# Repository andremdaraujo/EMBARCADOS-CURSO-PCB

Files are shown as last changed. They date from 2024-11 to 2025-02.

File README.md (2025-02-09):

# PROJETO DE PCB PARA SISTEMAS EMBARCADOS
  
Esta é uma placa de desenvolvimento educacional concebida como parte curso 
[**Projeto e PCB para Sistemas Embarcados**]( https://cursos.embarcados.com.br/cursos/projeto-de-pcb-para-sistemas-embarcados/). 
O curso é oferecido em parceria com o [**Portal Embarcados**](https://embarcados.com.br/).
Durante o curso, todas as etapas de projeto e desenvolvimento desta placa são mostradas, passo a passo. 
Neste repositório, é possível acessar a todos os arquivos de projeto e fabricação.

## Licença
Este é um projeto Open Source, licenciado sob a CERN-OHL-P. Mais detalhes em [LICENSE.md](./LICENSE.md).  
A placa desenvolvida durante o curso foi baseada no projeto [**STM32 Explorer Board - STM32XP**](https://github.com/MechatronixLab/STM32XP), 
que também é licenciado conforme a CERN-OHL-P e certificado pela OSWHA ([OSHW BR000018](https://certification.oshwa.org/br000018.html)).

## Especificações da placa

A placa é baseado no [**STM32F411**](https://www.st.com/en/microcontrollers-microprocessors/stm32f411.html), mais especificamente, o [**STM32F411RET6**](https://www.st.com/en/microcontrollers-microprocessors/stm32f411re.html).
Além disso, a placa apresenta alguns componentes comumente usados em sistemas embarcados, como:
- Conversores DC-DC
- Display OLED, conectado ao MCU via I²C
- LEDs RGB
- Áudio (Buzer Piezoelérico), controlada via PWM
- ADC externo com filtros antialiasing analógicos
- USB 1.1 Full Speed via conector Tipo C
- Cartão Micro SD para fácil armazenamento de dados, conectado ao MCU via SPI
- Botões conectados a pinos de entrada do MCU, além de botões para RESET e BOOT
- Vários pinos de GPIO roteados para conectores/pinos de breakout
- Bateria CR2032 para operação RTC

A placa pode ser utilizada em modo Standalone ou conectada a uma protoboard, dependendo da escolha de conectores:

Top

Bottom

Protoboard
  
## Firmware

Esta placa pode executar a aplicação de demonstração desenvolvida no projeto [STM32 Explorer Board - STM32XP](https://github.com/MechatronixLab/STM32XP).

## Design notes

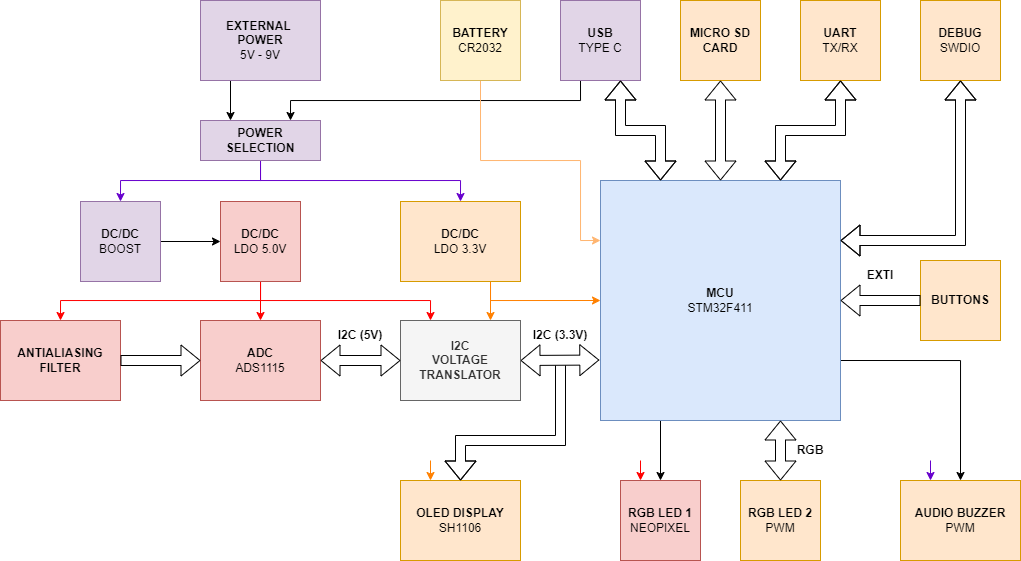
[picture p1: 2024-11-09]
DOC/PROTOTYPE/STM32XP REV.00 - HARDWARE BLOCK DIAGRAM.png

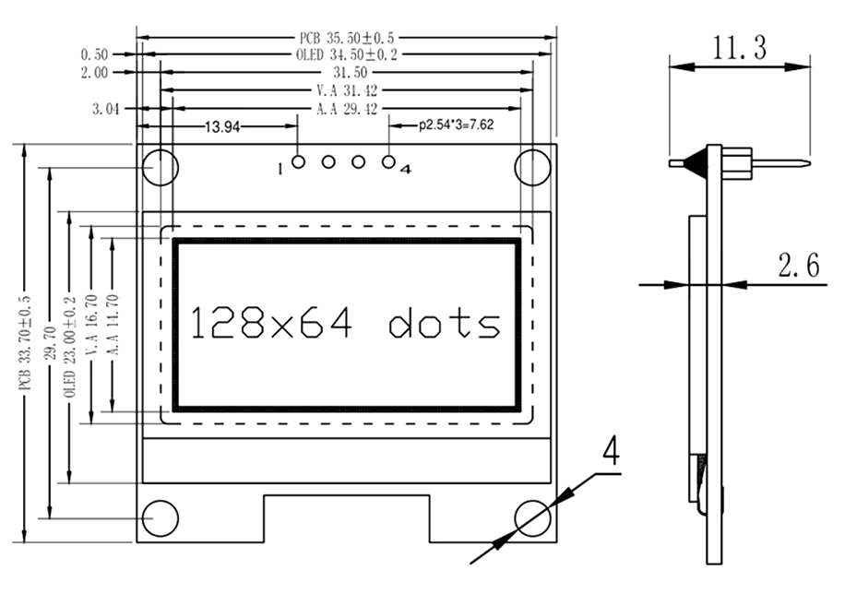
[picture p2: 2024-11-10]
DOC/DATASHEETS/OLED 1.3in - MECHANICAL DRAWING.png

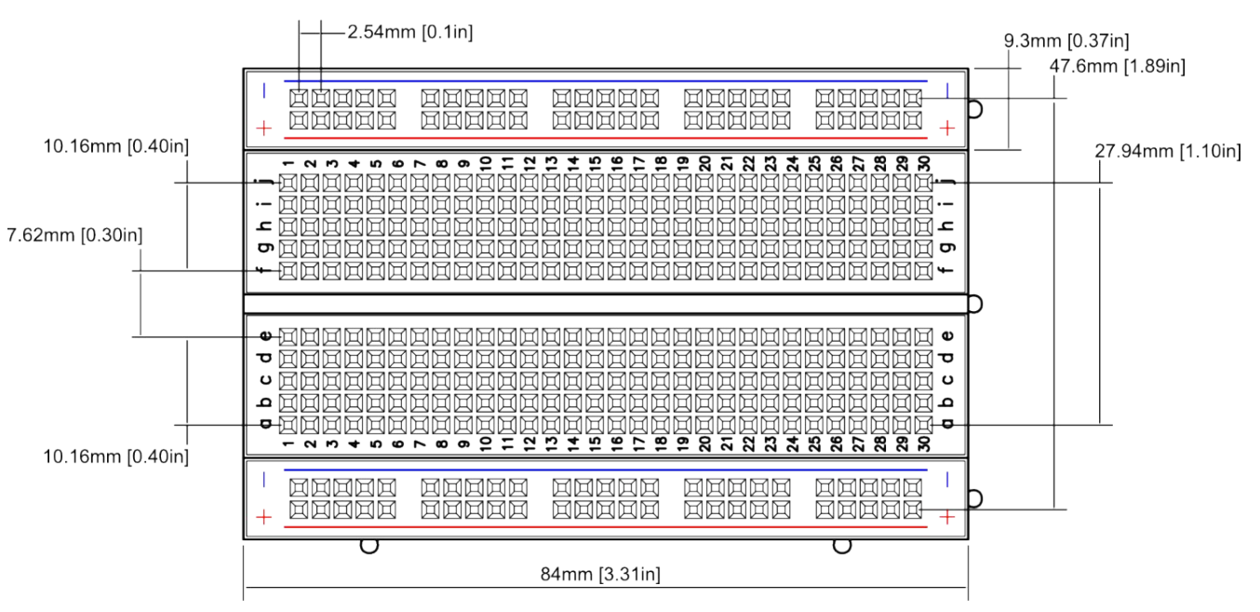
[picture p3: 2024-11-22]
HARDWARE/3D MODELS/p-pc-bb400_dimensions.png

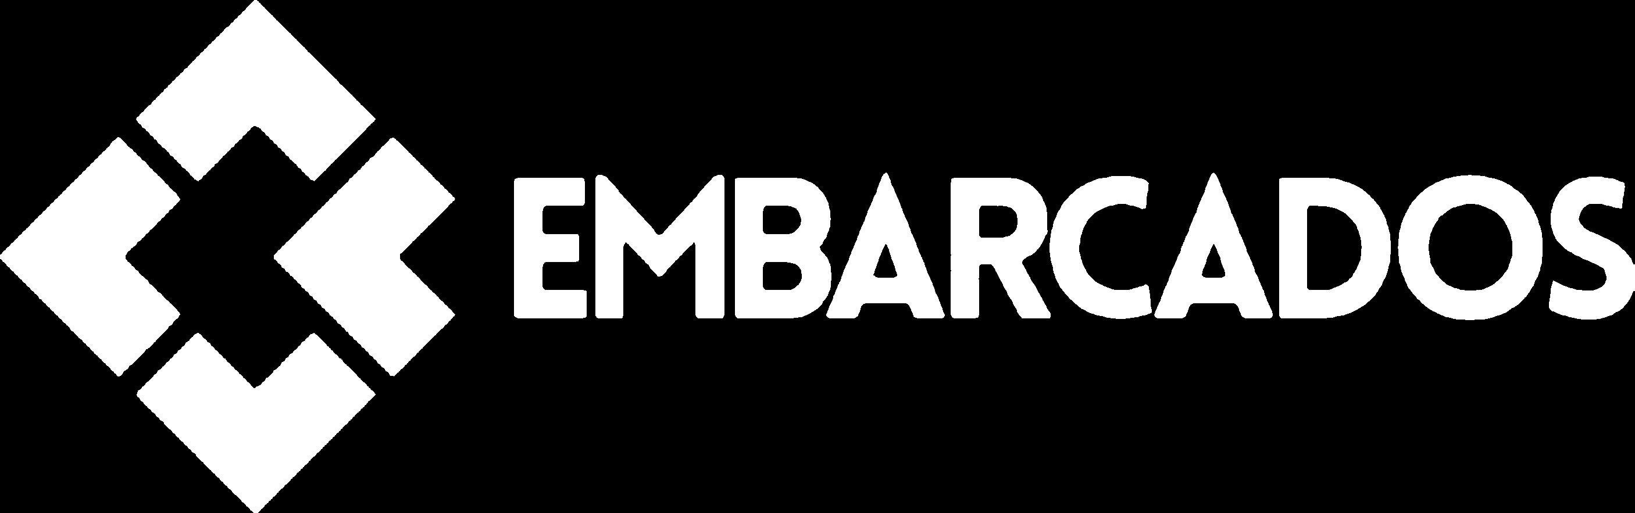
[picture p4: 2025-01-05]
DOC/IMAGES/EMBARCADOS BW.bmp

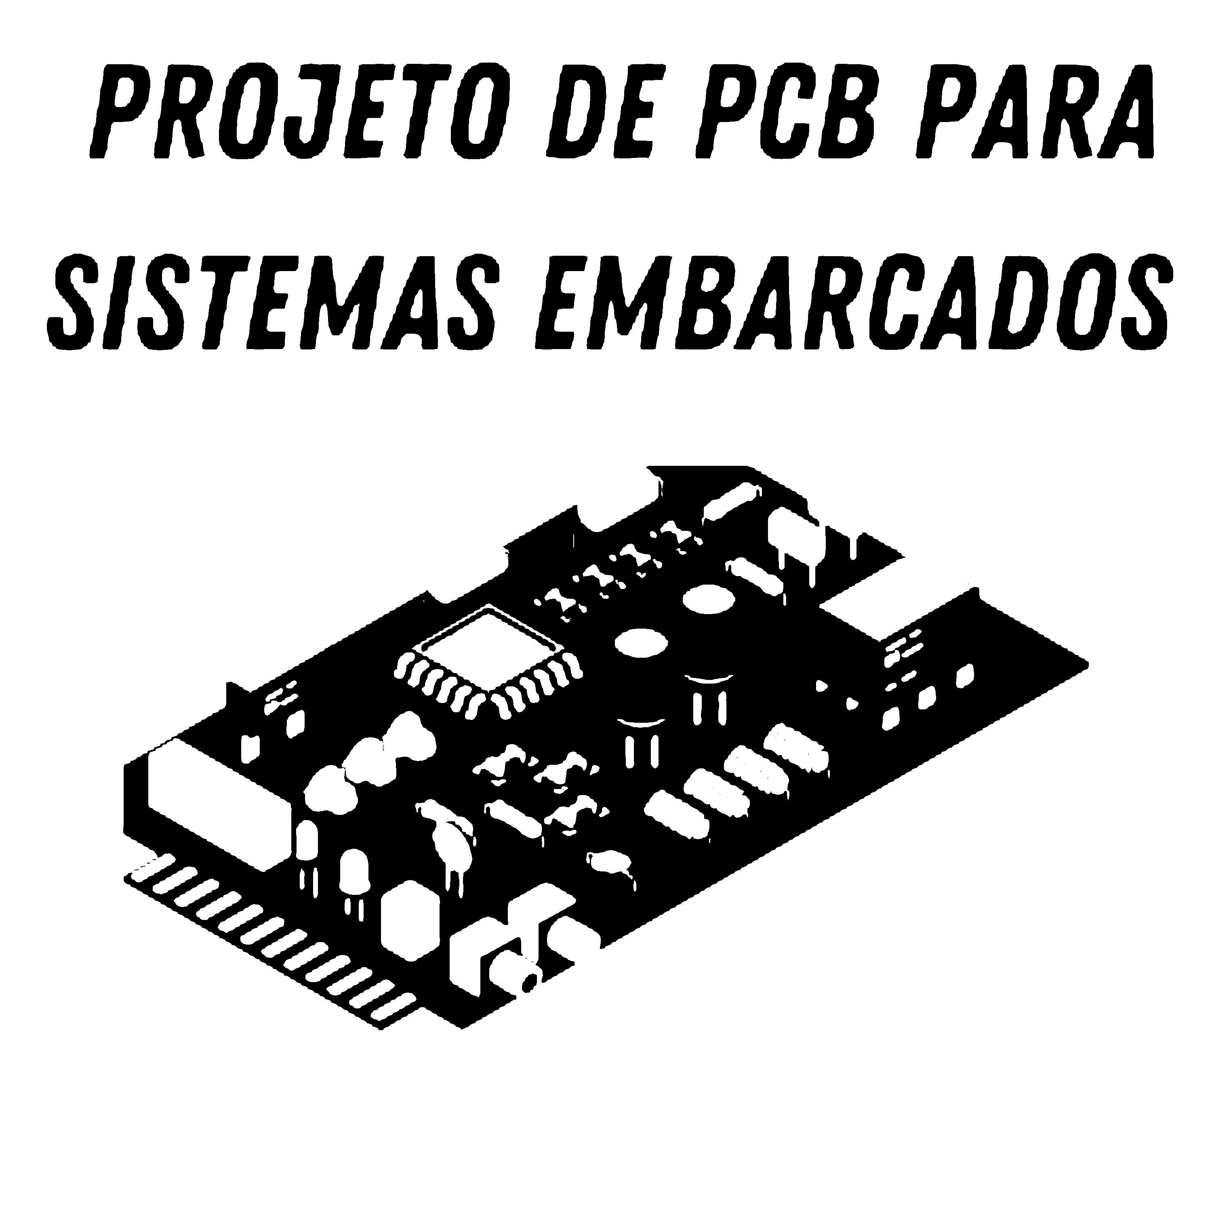
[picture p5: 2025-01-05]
DOC/IMAGES/CURSO PCB BW.bmp

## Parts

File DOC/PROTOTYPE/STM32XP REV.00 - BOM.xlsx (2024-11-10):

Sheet: STM32XP - BOM REV.00
 |  |  |  |  | SPEC |  |  |  |  | JLCPCB
# | DESIGNATOR | VALUE | FOOTPRINT | QTY. | MPN | MANUFACTURER | DATASHEET | 3D MODEL | NOTES | LCSC Part # | LCSC MPN | LCSC MANUFACTURER
1 | BT1 | CR2032 | CR2032 | 1 | 79527141 | WÜRTH ELEKTRONIK | https://www.we-online.com/components/products/datasheet/79527141.pdf | https://www.we-online.com/components/products/download/79527141%20%28rev1%29.igs | - | - | - | -
2 | C1, C10, C13, C19, C2, C27, C29, C36, C37, C4, C40, C44, C6, C7, C8, C9 | 10uF 16V | CAP_0805 | 16 | KGM21AR71C106K | KYOCERA/AVX | https://datasheets.kyocera-avx.com/KGM_X7R.pdf | KICAD CAP 0603 | - | C15850 (https://www.lcsc.com/product-detail/Multilayer-Ceramic-Capacitors-MLCC-SMD-SMT_Samsung-Electro-Mechanics-CL21A106KAYNNNE_C15850.html) | CL21A106KAYNNNE | SAMSUNG
3 | C11, C12, C17, C18, C20, C21, C22, C23, C24, C26, C28, C3, C30, C32, C33, C34, C35, C38, C39, C41, C42, C43, C45, C5 | 100nF 50V | CAP_0603 | 24 | KGM15BR71H104K | KYOCERA/AVX | https://datasheets.kyocera-avx.com/KGM_X7R.pdf | KICAD CAP 0603 | - | C14663 (https://www.lcsc.com/product-detail/Multilayer-Ceramic-Capacitors-MLCC-SMD-SMT_YAGEO-CC0603KRX7R9BB104_C14663.html) | CC0603KRX7R9BB104 | YAGEO
4 | C14, C15, C25, C31 | 10pF 50V | CAP_0603 | 4 | KGM15ACG1H100G | KYOCERA/AVX | https://datasheets.kyocera-avx.com/C0GNP0-KGM.pdf | KICAD CAP 0603 | - | C1634 (https://www.lcsc.com/product-detail/Multilayer-Ceramic-Capacitors-MLCC-SMD-SMT_Samsung-Electro-Mechanics-CL10C100JB8NNNC_C1634.html) | CL10C100JB8NNNC | SAMSUNG
5 | C16 | 680nF 16V | CAP_0603 | 1 | KGM15BR71C684M | KYOCERA/AVX | https://datasheets.kyocera-avx.com/KGM_X7R.pdf | KICAD CAP 0603 | - | C327005 (https://www.lcsc.com/product-detail/Multilayer-Ceramic-Capacitors-MLCC-SMD-SMT_YAGEO-CC0603KRX5R8BB684_C327005.html) | CC0603KRX5R8BB684 | YAGEO
6 | D1, D3, D4, D7, D8 | LED | LED_0603 | 5 | 150060SS55040 | WÜRTH ELEKTRONIK | https://www.we-online.com/components/products/datasheet/150060SS55040.pdf | KICAD LED 0603 | - | C128052 (https://www.lcsc.com/product-detail/LED-Indication-Discrete_Everlight-Elec-19-213-R6C-AM2P1VY-3T_C128052.html) | 19-213/R6C-AM2P1VY/3T | EVERLIGHT
7 | D10 | 150505M173300 | WE 150505M173300 | 1 | 150505M173300 | WÜRTH ELEKTRONIK | https://www.we-online.com/components/products/datasheet/150505M173300.pdf | https://www.we-online.com/components/products/download/Download_IGS-WL-SFTW-150505M173300%20%28rev1%29.igs | - | - | - | -
8 | D2 | STPS1L40-Y | D_SOD-123 | 1 | STPS1L40ZFY | STMICROELECTRONICS | https://www.st.com/resource/en/datasheet/stps1l40-y.pdf | KICAD SOD-123 | - | C82544 (https://www.lcsc.com/product-detail/Schottky-Diodes_Diodes-Incorporated-1N5819HW-7-F_C82544.html) | 1N5819HW-7-F | DIODES INCORPORATED
9 | D5 | WS2812B | LED_WS2812B_PLCC4_5.0x5.0mm_P3.2mm | 1 | 1315050930002 | WÜRTH ELEKTRONIK | https://www.we-online.com/components/products/datasheet/1315050930002.pdf | https://www.we-online.com/components/products/download/IGS_WL-ICLED_1315050930002%20%28rev1%29.igs | - | - | - | -
10 | D6 | BAT54C | SOT-23 | 1 | BAT54C-7-F | DIODES INCORPORATED | https://www.diodes.com/datasheet/download/BAT54C.pdf | KICAD SOT-23-3 | CHANGE TO 2X 1N5819HW | C916424 (https://www.lcsc.com/product-detail/Schottky-Diodes_JSMSEMI-BAT54C_C916424.html) | BAT54C | JSMSEMI
11 | D9 | ESDA6V1-5SC6 | SOT-23-6 | 1 | ESDA6V1-5SC6 | STMICROELECTRONICS | https://www.st.com/resource/en/datasheet/esda6v1-5sc6.pdf | KICAD SOT-23-6 | - | C2827672 (https://www.lcsc.com/product-detail/ESD-and-Surge-Protection-TVS-ESD_TECH-PUBLIC-ESDA6V1-5SC6_C2827672.html) | ESDA6V1-5SC6 | TECH PUBLIC
12 | FB1, FB2, FB3 | 600R | 0603 | 3 | 742792651 | WÜRTH ELEKTRONIK | https://www.we-online.com/components/products/datasheet/742792651.pdf | KICAD FB 0603 | - | C963865 (https://www.lcsc.com/product-detail/Ferrite-Beads_HYHONGYEX-ACMS160808A1213A_C963865.html) | ACMS160808A1213A | HYHONGYEX
13 | FID1, FID2, FID3 | Fiducial | Fiducial_0.75mm_Mask1.5mm | 3 | - | - | - | - | DO NOT PLACE | - | - | -
14 | H1, H2, H3, H4 | MountingHole | MountingHole_3.2mm_M3 | 4 | - | - | - | - | DO NOT PLACE | - | - | -
15 | J1, J6 | Conn_01x20_Socket | PinSocket_1x20_P2.54mm_Horizontal | 2 | 613020143121 | WÜRTH ELEKTRONIK | https://www.we-online.com/components/products/datasheet/613020143121.pdf | https://www.we-online.com/components/products/download/613020143121%20%28rev1%29.igs | THRU HOLE | - | - | -
16 | J2 | Jack-DC | BarrelJack_GCT_DCJ200-10-A_Horizontal | 1 | 694108301002 | WÜRTH ELEKTRONIK | https://www.we-online.com/components/products/datasheet/694108301002.pdf | https://www.we-online.com/components/products/download/Download_IGES_694108301002%20%28rev1%29.iges | THRU HOLE | - | - | -
17 | J3 | Conn_02x05_Odd_Even | PinSocket_2x05_P2.54mm_Horizontal | 1 | 613010243121 | WÜRTH ELEKTRONIK | https://www.we-online.com/components/products/datasheet/613010243121.pdf | https://www.we-online.com/components/products/download/Downloads_613010243121%20%28rev1%29.iges | THRU HOLE | - | - | -
18 | J4 | USB TYPE C | USB_C_Receptacle_G-Switch_GT-USB-7010ASV | 1 | 629722000214 | WÜRTH ELEKTRONIK | https://www.we-online.com/components/products/datasheet/629722000214.pdf | https://www.we-online.com/components/products/download/IGES_629722000214%20%28rev1%29.iges | - | C2927038 (https://www.lcsc.com/product-detail/USB-Connectors_DEALON-USB-TYPE-C-018_C2927038.html) | USB-TYPE-C-018 | DEALON
19 | J5 | MICRO SD | WE 693071020811 | 1 | 693071020811 | WÜRTH ELEKTRONIK | https://www.we-online.com/components/products/datasheet/693071020811.pdf | https://www.we-online.com/components/products/download/Download_IGES_693071020811%20%28rev1%29.iges | - | C19189038 (https://www.lcsc.com/product-detail/SD-Card-Memory-Card-Connector_hanxia-HX-TF-CARD-H1-8-SY_C19189038.html) | HX TF-CARD H1.8 SY | HANXIA
20 | JP1 | 9V | SolderJumper | 1 | - | - | - | - | DO NOT PLACE | - | - | -
21 | JP2 | VSEL | SolderJumper | 1 | - | - | - | - | DO NOT PLACE | - | - | -
22 | L1 | 10uH | WE 74404024100 | 1 | 74404024100 | WÜRTH ELEKTRONIK | https://www.we-online.com/components/products/datasheet/74404024100.pdf | https://www.we-online.com/components/products/download/WE-LQS_252012%20%28rev1%29.igs | - | C520138 (https://www.lcsc.com/product-detail/Power-Inductors_Cybermax-CMLW252012P100MST_C520138.html) | CMLW252012P100MST | CYBERMAX
23 | L2 | 744232090 | WE 744232090 | 1 | 744232090 | WÜRTH ELEKTRONIK | https://www.we-online.com/components/products/datasheet/744232090.pdf | https://www.we-online.com/components/products/download/WE-CNSW_1206_CNSW%20%28rev1%29.igs | - | - | - | -
24 | L3 | L_Small | IND_0603 | 1 | 742792651 | WÜRTH ELEKTRONIK | https://www.we-online.com/components/products/datasheet/742792651.pdf | KICAD FB 0603 | - | C963865 (https://www.lcsc.com/product-detail/Ferrite-Beads_HYHONGYEX-ACMS160808A1213A_C963865.html) | ACMS160808A1213A | HYHONGYEX
25 | LS1 | 78dB 4kHz | PKM13EPYH4000-A0 | 1 | PKM13EPYH4000-A0 | MURATA | https://www.murata.com/en-us/products/productdetail?partno=PKM13EPYH4000-A0 | https://www.murata.com/en-us/products/productdetail?partno=PKM13EPYH4000-A0 | THRU HOLE | - | - | -
26 | Q1, Q2, Q3 | 2N7002 | SOT-23 | 3 | 2N7002K-7 | DIODES INCORPORATED | https://www.diodes.com/datasheet/download/2N7002K.pdf | KICAD SOT-23-3 | - | C8545 (https://www.lcsc.com/product-detail/MOSFETs_Jiangsu-Changjing-Electronics-Technology-Co-Ltd-2N7002_C8545.html) | 2N7002 | JIANGSU CHANGJING
27 | R1, R11, R13, R14, R18, R2, R21, R24, R25, R26, R27, R32, R35, R36, R37, R39, R40, R41, R45, R46, R47, R48, R49, R50, R51, R52, R53 | 10K 1% | RES_0603 | 27 | CRCW060310K0FK | VISHAY | https://www.we-online.com/components/products/datasheet/61300411821.pdf | KICCAD RES 0603 | - | C25804 (https://www.lcsc.com/product-detail/Chip-Resistor-Surface-Mount_UNI-ROYAL-Uniroyal-Elec-0603WAF1002T5E_C25804.html) | 0603WAF1002T5E | UNI-ROYAL
28 | R10, R22, R30, R31, R33, R34, R8, R9 | 1K 1% | RES_0603 | 8 | CRCW06031K00FK | VISHAY | https://www.we-online.com/components/products/datasheet/61300411821.pdf | KICCAD RES 0603 | - | C21190 (https://www.lcsc.com/product-detail/Chip-Resistor-Surface-Mount_UNI-ROYAL-Uniroyal-Elec-0603WAF1001T5E_C21190.html) | 0603WAF1001T5E | UNI-ROYAL
29 | R12, R15 | 2.2K 1% | RES_0603 | 2 | CRCW06032K20FK | VISHAY | https://www.we-online.com/components/products/datasheet/61300411821.pdf | KICCAD RES 0603 | - | C4190 (https://www.lcsc.com/product-detail/Chip-Resistor-Surface-Mount_UNI-ROYAL-Uniroyal-Elec-0603WAF2201T5E_C4190.html) | 0603WAF2201T5E | UNI-ROYAL
30 | R16, R17, R19, R20, R38, R4, R42, R43, R44, R5, R6, R7 | 51R 1% | RES_0603 | 12 | CRCW060351R0FK | VISHAY | https://www.we-online.com/components/products/datasheet/61300411821.pdf | KICCAD RES 0603 | - | C23197 (https://www.lcsc.com/product-detail/Chip-Resistor-Surface-Mount_UNI-ROYAL-Uniroyal-Elec-0603WAF510JT5E_C23197.html) | 0603WAF510JT5E | UNI-ROYAL
31 | R23, R28 | 5.1K 1% | RES_0603 | 2 | CRCW06035K10FK | VISHAY | https://www.we-online.com/components/products/datasheet/61300411821.pdf | KICCAD RES 0603 | - | C23186 (https://www.lcsc.com/product-detail/Chip-Resistor-Surface-Mount_UNI-ROYAL-Uniroyal-Elec-0603WAF5101T5E_C23186.html) | 0603WAF5101T5E | UNI-ROYAL
32 | R29 | 0R | RES_0603 | 1 | CRCW06030000Z0 | VISHAY | https://www.we-online.com/components/products/datasheet/61300411821.pdf | KICCAD RES 0603 | - | C21189 (https://www.lcsc.com/product-detail/Chip-Resistor-Surface-Mount_UNI-ROYAL-Uniroyal-Elec-0603WAF0000T5E_C21189.html) | 0603WAF0000T5E | UNI-ROYAL
33 | R3 | 6K2 1% | RES_0603 | 1 | CRCW06036K20FK | VISHAY | https://www.we-online.com/components/products/datasheet/61300411821.pdf | KICCAD RES 0603 | - | C4260 (https://www.lcsc.com/product-detail/Chip-Resistor-Surface-Mount_UNI-ROYAL-Uniroyal-Elec-0603WAF6201T5E_C4260.html) | 0603WAF6201T5E | UNI-ROYAL
34 | SW1 | RST | SW_Push_1P1T_NO_CK_KSC6xxJ | 1 | PTS526SM20SMTR21 LFS | LITTELFUSE/C&K | https://www.ckswitches.com/media/2780/pts526.pdf | https://www.ckswitches.com/products/switches/product-details/Tactile/PTS526/PTS526SM20SMTR21%20LFS/ | ${KICAD8_3DMODEL_DIR}/Button_Switch_SMD.3dshapes/SW_SPST_TL3342.step | C318884 (https://www.lcsc.com/product-detail/Tactile-Switches_XKB-Connection-TS-1187A-B-A-B_C318884.html) | TS-1187A-B-A-B | XKB CONNECTION
35 | SW2 | UP | SW_Push_1P1T_NO_CK_KSC6xxJ | 1 | PTS526SM20SMTR21 LFS | LITTELFUSE/C&K | https://www.ckswitches.com/media/2780/pts526.pdf | https://www.ckswitches.com/products/switches/product-details/Tactile/PTS526/PTS526SM20SMTR21%20LFS/ | ${KICAD8_3DMODEL_DIR}/Button_Switch_SMD.3dshapes/SW_SPST_TL3342.step | C318884 (https://www.lcsc.com/product-detail/Tactile-Switches_XKB-Connection-TS-1187A-B-A-B_C318884.html) | TS-1187A-B-A-B | XKB CONNECTION
36 | SW3 | LEFT | SW_Push_1P1T_NO_CK_KSC6xxJ | 1 | PTS526SM20SMTR21 LFS | LITTELFUSE/C&K | https://www.ckswitches.com/media/2780/pts526.pdf | https://www.ckswitches.com/products/switches/product-details/Tactile/PTS526/PTS526SM20SMTR21%20LFS/ | ${KICAD8_3DMODEL_DIR}/Button_Switch_SMD.3dshapes/SW_SPST_TL3342.step | C318884 | TS-1187A-B-A-B | XKB CONNECTION
37 | SW4 | CENTER | SW_Push_1P1T_NO_CK_KSC6xxJ | 1 | PTS526SM20SMTR21 LFS | LITTELFUSE/C&K | https://www.ckswitches.com/media/2780/pts526.pdf | https://www.ckswitches.com/products/switches/product-details/Tactile/PTS526/PTS526SM20SMTR21%20LFS/ | ${KICAD8_3DMODEL_DIR}/Button_Switch_SMD.3dshapes/SW_SPST_TL3342.step | C318884 | TS-1187A-B-A-B | XKB CONNECTION
38 | SW5 | RIGHT | SW_Push_1P1T_NO_CK_KSC6xxJ | 1 | PTS526SM20SMTR21 LFS | LITTELFUSE/C&K | https://www.ckswitches.com/media/2780/pts526.pdf | https://www.ckswitches.com/products/switches/product-details/Tactile/PTS526/PTS526SM20SMTR21%20LFS/ | ${KICAD8_3DMODEL_DIR}/Button_Switch_SMD.3dshapes/SW_SPST_TL3342.step | C318884 | TS-1187A-B-A-B | XKB CONNECTION
39 | SW6 | BUTTON 1 | SW_Push_1P1T_NO_CK_KSC6xxJ | 1 | PTS526SM20SMTR21 LFS | LITTELFUSE/C&K | https://www.ckswitches.com/media/2780/pts526.pdf | https://www.ckswitches.com/products/switches/product-details/Tactile/PTS526/PTS526SM20SMTR21%20LFS/ | ${KICAD8_3DMODEL_DIR}/Button_Switch_SMD.3dshapes/SW_SPST_TL3342.step | C318884 | TS-1187A-B-A-B | XKB CONNECTION
40 | SW7 | BUTTON 2 | SW_Push_1P1T_NO_CK_KSC6xxJ | 1 | PTS526SM20SMTR21 LFS | LITTELFUSE/C&K | https://www.ckswitches.com/media/2780/pts526.pdf | https://www.ckswitches.com/products/switches/product-details/Tactile/PTS526/PTS526SM20SMTR21%20LFS/ | ${KICAD8_3DMODEL_DIR}/Button_Switch_SMD.3dshapes/SW_SPST_TL3342.step | C318884 | TS-1187A-B-A-B | XKB CONNECTION
41 | SW8 | DOWN | SW_Push_1P1T_NO_CK_KSC6xxJ | 1 | PTS526SM20SMTR21 LFS | LITTELFUSE/C&K | https://www.ckswitches.com/media/2780/pts526.pdf | https://www.ckswitches.com/products/switches/product-details/Tactile/PTS526/PTS526SM20SMTR21%20LFS/ | ${KICAD8_3DMODEL_DIR}/Button_Switch_SMD.3dshapes/SW_SPST_TL3342.step | C318884 | TS-1187A-B-A-B | XKB CONNECTION
42 | TP1, TP13, TP14, TP4 | GND | TestPoint_Keystone_5000-5004_Miniature | 4 | - | - | - | - | DO NOT PLACE | - | - | -
43 | TP10 | +3.3VA | TestPoint_Keystone_5000-5004_Miniature | 1 | - | - | - | - | DO NOT PLACE | - | - | -
44 | TP11 | +5VA | TestPoint_Keystone_5000-5004_Miniature | 1 | - | - | - | - | DO NOT PLACE | - | - | -
45 | TP12 | +VCORE | TestPoint_Keystone_5000-5004_Miniature | 1 | - | - | - | - | DO NOT PLACE | - | - | -
46 | TP15 | PD2 | TestPoint_THTPad_D1.0mm_Drill0.5mm | 1 | - | - | - | - | DO NOT PLACE | - | - | -
47 | TP16 | PC11 | TestPoint_THTPad_D1.0mm_Drill0.5mm | 1 | - | - | - | - | DO NOT PLACE | - | - | -
48 | TP17 | PC12 | TestPoint_THTPad_D1.0mm_Drill0.5mm | 1 | - | - | - | - | DO NOT PLACE | - | - | -
49 | TP18 | PB5 | TestPoint_THTPad_D1.0mm_Drill0.5mm | 1 | - | - | - | - | DO NOT PLACE | - | - | -
50 | TP19 | PB4 | TestPoint_THTPad_D1.0mm_Drill0.5mm | 1 | - | - | - | - | DO NOT PLACE | - | - | -
51 | TP2 | +5V | TestPoint_Keystone_5000-5004_Miniature | 1 | - | - | - | - | DO NOT PLACE | - | - | -
52 | TP20 | PC13 | TestPoint_THTPad_D1.0mm_Drill0.5mm | 1 | - | - | - | - | DO NOT PLACE | - | - | -
53 | TP21 | PB10 | TestPoint_THTPad_D1.0mm_Drill0.5mm | 1 | - | - | - | - | DO NOT PLACE | - | - | -
54 | TP3 | +3.3V | TestPoint_Keystone_5000-5004_Miniature | 1 | - | - | - | - | DO NOT PLACE | - | - | -
55 | TP5 | +9V | TestPoint_Keystone_5000-5004_Miniature | 1 | - | - | - | - | DO NOT PLACE | - | - | -
56 | TP6 | +VSEL | TestPoint_Keystone_5000-5004_Miniature | 1 | - | - | - | - | DO NOT PLACE | - | - | -
57 | TP7 | +VEXT | TestPoint_Keystone_5000-5004_Miniature | 1 | - | - | - | - | DO NOT PLACE | - | - | -
58 | TP8 | +VBUS | TestPoint_Keystone_5000-5004_Miniature | 1 | - | - | - | - | DO NOT PLACE | - | - | -
59 | TP9 | +3VBAT | TestPoint_Keystone_5000-5004_Miniature | 1 | - | - | - | - | DO NOT PLACE | - | - | -
60 | U1 | AMS1117-5.0 | SOT-223-3 | 1 | LD1117S50TR | STMICROELECTRONICS | https://www.st.com/resource/en/datasheet/ld1117.pdf | KICAD STO-223-3 | - | C6187 (https://www.lcsc.com/product-detail/Voltage-Regulators-Linear-Low-Drop-Out-LDO-Regulators_Advanced-Monolithic-Systems-AMS1117-5-0_C6187.html) | AMS1117-5.0 | ADVANCED MONOLITHIC SYSTEMS
61 | U2 | AMS1117-3.3 | SOT-223-3 | 1 | LD1117S33TR | STMICROELECTRONICS | https://www.st.com/resource/en/datasheet/ld1117.pdf | KICAD STO-223-3 | - | C6186 (https://www.lcsc.com/product-detail/Voltage-Regulators-Linear-Low-Drop-Out-LDO-Regulators_Advanced-Monolithic-Systems-AMS1117-3-3_C6186.html) | AMS1117-3.3 | ADVANCED MONOLITHIC SYSTEMS
62 | U3 | AP3012 | SOT-23-5 | 1 | AP3012KTR-E1 | DIODES INCORPORATED | https://www.diodes.com/datasheet/download/AP3012.pdf | KICAD SOT-23-5 | - | C460356 (https://www.lcsc.com/product-detail/DC-DC-Converters_Diodes-Incorporated-AP3012KTR-E1_C460356.html) | AP3012KTR-E1 | DIODES INCORPORATED
63 | U4 | OLED 128x64 1.3" | OLED 128x64 1.3in | 1 | 61300411821 | WÜRTH ELEKTRONIK | https://www.we-online.com/components/products/datasheet/61300411821.pdf | https://www.we-online.com/components/products/download/61300411821%20%28rev1%29.iges | THRU HOLE; https://grabcad.com/library/oled-screen-1-3-1 | - | - | -
64 | U5 | USBLC6-2SC6 | SOT-23-6 | 1 | USBLC6-2SC6 | STMICROELECTRONICS | https://www.st.com/resource/en/datasheet/usblc6-2sc6y.pdf | KICAD SOT-23-6 | - | C2827654 (https://www.lcsc.com/product-detail/ESD-and-Surge-Protection-TVS-ESD_TECH-PUBLIC-USBLC6-2SC6_C2827654.html) | USBLC6-2SC6 | TECH PUBLIC
65 | U6 | LM324 | TSSOP-14_4.4x5mm_P0.65mm | 1 | LMV324IPT | STMICROELECTRONICS | https://www.st.com/resource/en/datasheet/lmv324.pdf | KICAD TSSOP-14 | - | C398929 (https://www.lcsc.com/product-detail/Operational-Amplifier_Texas-Instruments-LMV324IPWR_C398929.html) | LMV324IPWR | TEXAS INSTRUMENTS
66 | U7 | ADS1115IDGS | TSSOP-10_3x3mm_P0.5mm | 1 | ADS1115IDGSR | TEXAS INSTRUMENTS | https://www.ti.com/lit/ds/symlink/ads1115.pdf | KICAD TSSOP-10 | - | C37593 (https://www.lcsc.com/product-detail/Analog-to-Digital-Converters-ADC_Texas-Instruments-ADS1115IDGSR_C37593.html) | ADS1115IDGSR | TEXAS INSTRUMENTS
67 | U8 | STM32F411RETx | LQFP-64_10x10mm_P0.5mm | 1 | STM32F411RET6 | STMICROELECTRONICS | https://www.st.com/resource/en/datasheet/stm32f411re.pdf | KICAD LQFP-64 | - | C94355 (https://www.lcsc.com/product-detail/Microcontrollers-MCU-MPU-SOC_STMicroelectronics-STM32F411RET6_C94355.html) | STM32F411RET6 | STMICROELECTRONICS
68 | Y1 | 32.768kHz 12.5pF | XTAL_2PIN_3.2x1.5mm | 1 | ABS06-32.768KHZ-T | ABRACON/FOX | https://abracon.com/Resonators/ABS06.pdf | KICAD XTAL 3.2x1.5 | - | C5563819 (https://www.lcsc.com/product-detail/Crystals_HCI-3131M-32768DT06LLL_C5563819.html) | 3131M-32768DT06LLL | HCI
69 | Y2 | 12MHz 20ppm 18pF | XTAL_4PIN_3.2x2.5mm | 1 | ABM8-12.000MHZ-D2Y-T | ABRACON/FOX | https://abracon.com/Resonators/abm8.pdf | KICAD XTAL 3.2x2.5 | - | C6071564 (https://www.lcsc.com/product-detail/Crystals_SST-3225-12M-18PF-20PPM_C6071564.html) | 3225 12M 18PF 20PPM | SST
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

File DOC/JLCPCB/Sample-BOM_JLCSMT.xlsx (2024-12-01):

Comment | Designator | Footprint | JLCPCB Part #（optional）
100uF | C1 | CAP-SMD_L3.5-W2.8 | C16133
15K | R5,R6 | R0603 | C22809
DC-005-20A_C136744 | DC1 | DC-IN-TH_DC-005-20A | C136744
Header-Female-2.54_1x8 | P2,P3 | HDR-TH_8P-P2.54-V | C27438
K2-1102DP-C4SW-04 | SW1 | KEY-TH_4P-L6.0-W6.0-P4.50-LS6.5 | C110153
ATMEGA328P-PU | U1 | DIP-28_L34.6-W7.3-P2.54-LS10.2-BL | C33901
670688000 | USB1 | USB-B-TH_67068-8000 | C114097

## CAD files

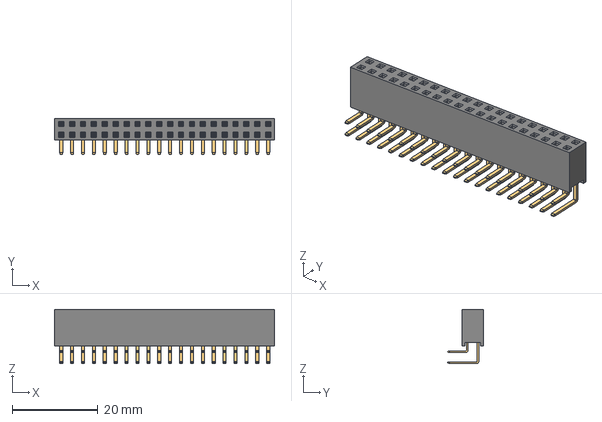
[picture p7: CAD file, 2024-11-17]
HARDWARE/3D MODELS/WE 613040243121 (rev1).iges
51.3 x 8.30 x 12.6 mm

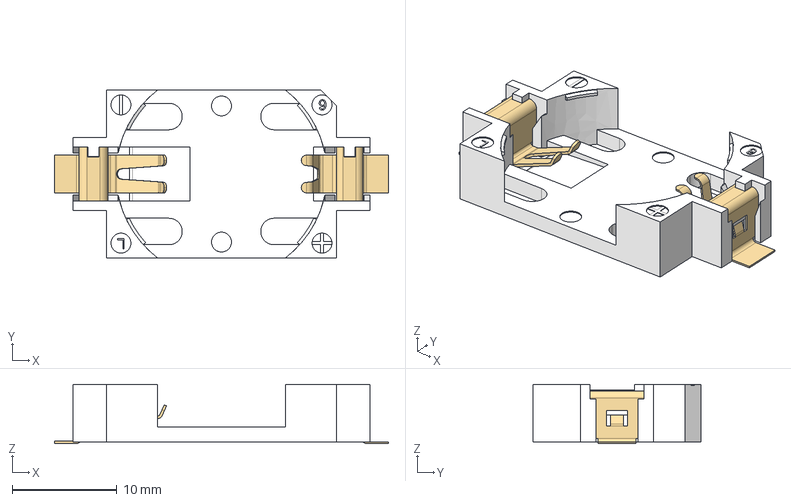
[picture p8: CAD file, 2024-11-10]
HARDWARE/3D MODELS/WE 79527141 (rev1).igs
31.9 x 16.0 x 5.65 mm

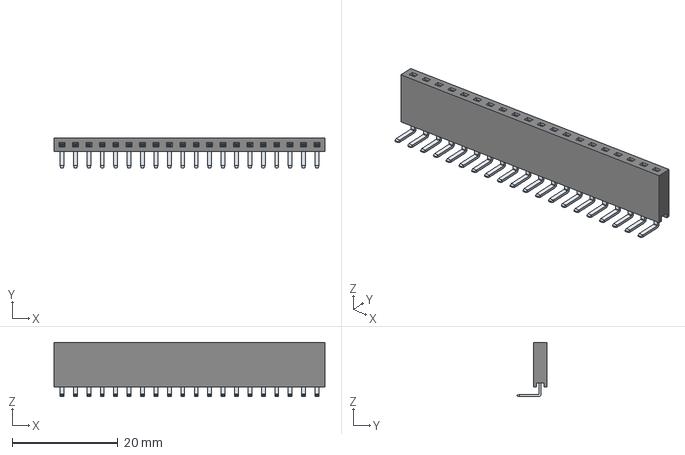
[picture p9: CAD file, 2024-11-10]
HARDWARE/3D MODELS/WE 613020143121 (rev1).igs
51.3 x 5.59 x 10.3 mm

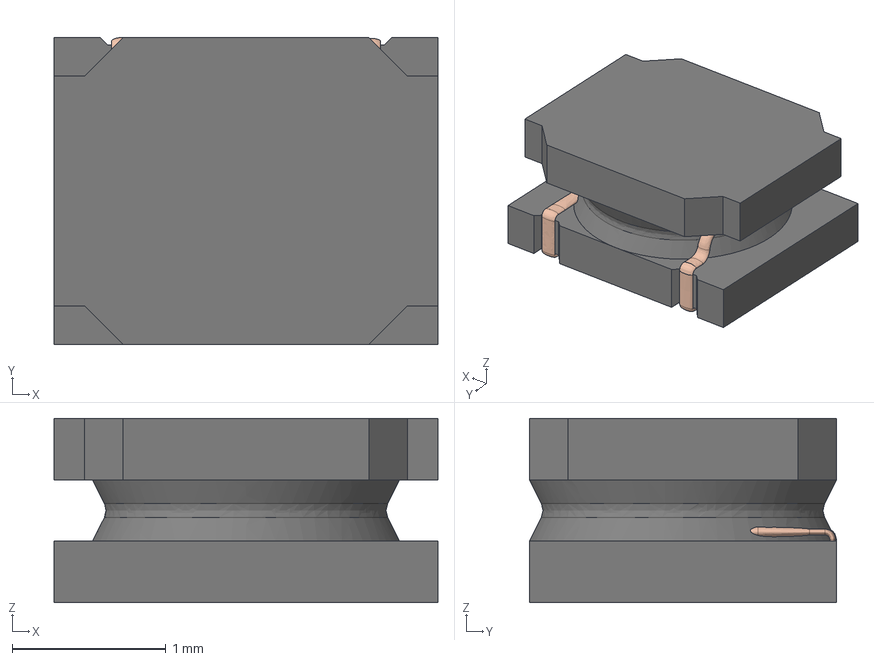
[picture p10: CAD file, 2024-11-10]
HARDWARE/3D MODELS/WE LQS_252012 (rev1).igs
2.50 x 2.00 x 1.20 mm

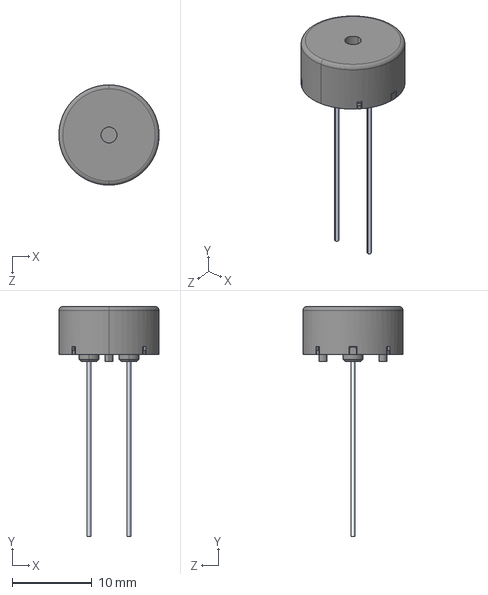
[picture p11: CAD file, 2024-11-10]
HARDWARE/3D MODELS/MURATA PKM13EPYH4000-A0.STEP
12.6 x 28.9 x 12.6 mm

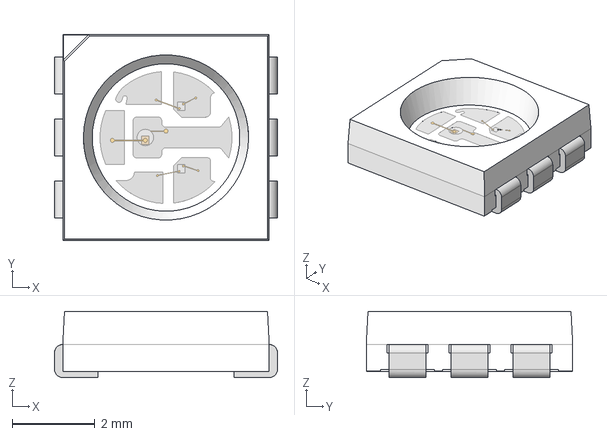
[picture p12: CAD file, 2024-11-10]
HARDWARE/3D MODELS/WE IGS-WL-SFTW-150505M173300 (rev1).igs
5.40 x 5.00 x 1.60 mm

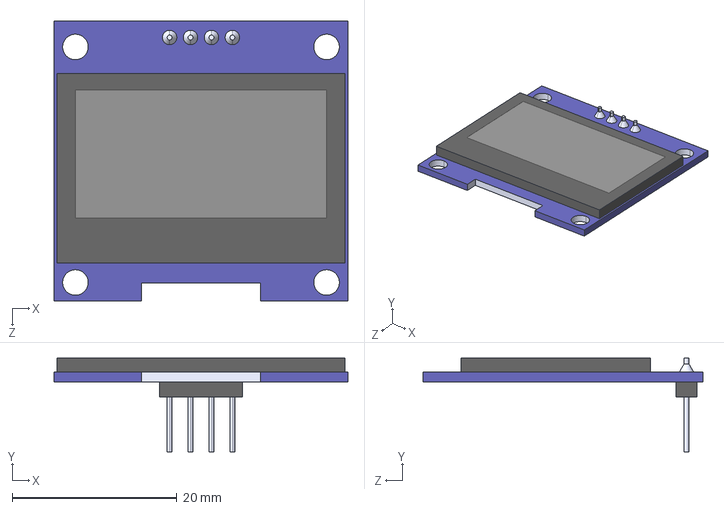
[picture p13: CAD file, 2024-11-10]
HARDWARE/3D MODELS/Display_OLED_SSD1306_1.3inch.STEP
35.7 x 11.4 x 34.0 mm

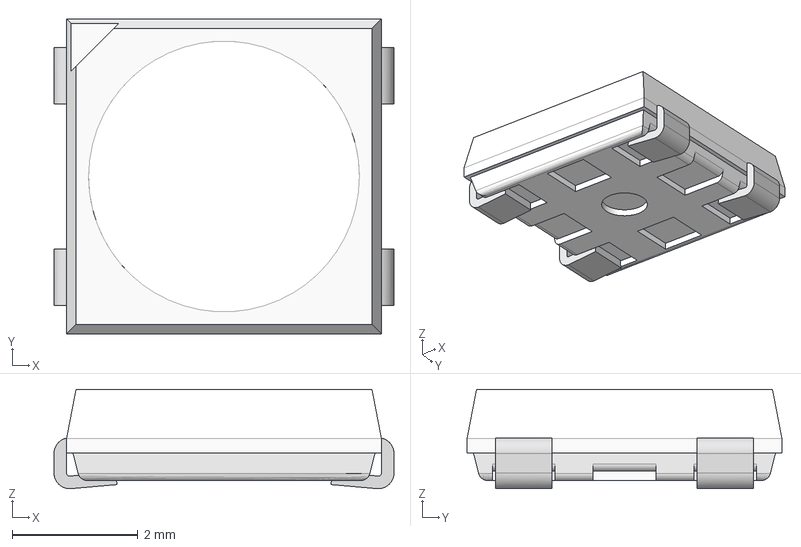
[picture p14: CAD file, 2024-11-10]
HARDWARE/3D MODELS/WE IGS_WL-ICLED_1315050930002 (rev1).igs
5.40 x 5.00 x 1.58 mm

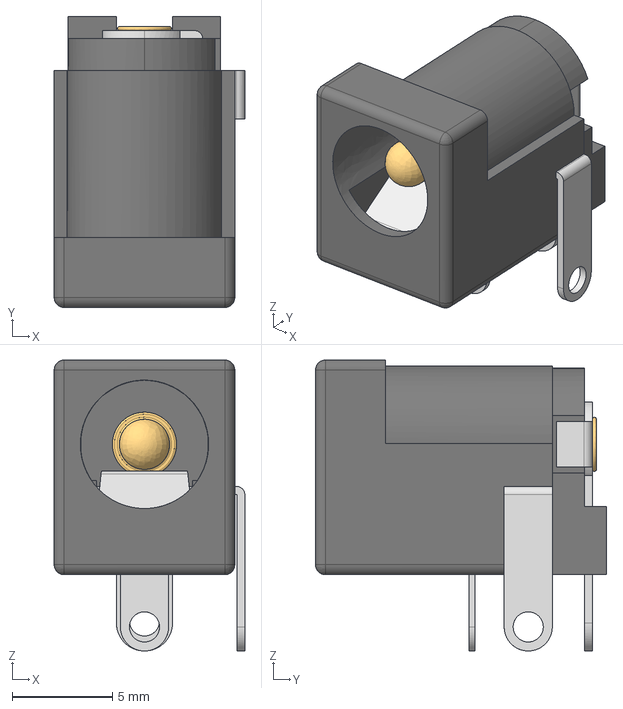
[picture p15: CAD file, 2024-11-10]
HARDWARE/3D MODELS/WE 694108301002 (rev1).iges
9.50 x 14.5 x 14.5 mm

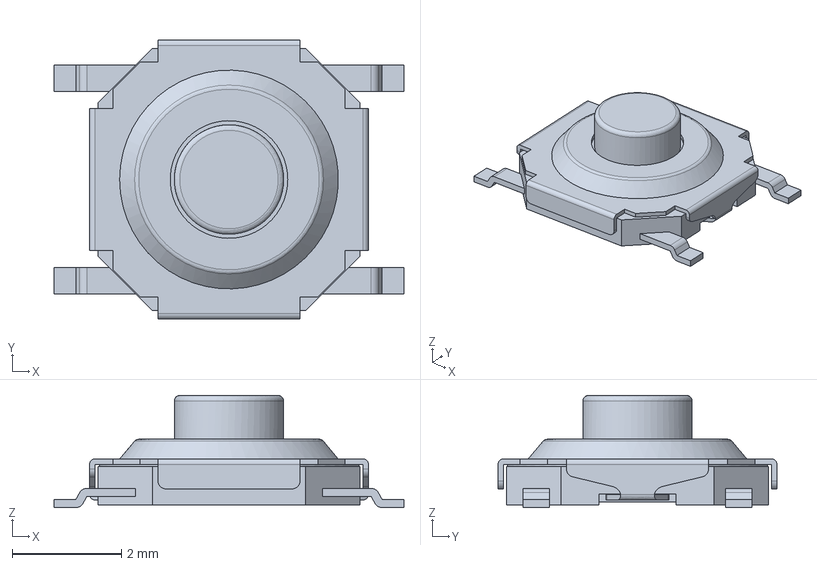
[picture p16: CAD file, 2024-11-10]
HARDWARE/3D MODELS/C&K PTS526SM20SMTR21LFS.igs
6.40 x 5.10 x 2.05 mm

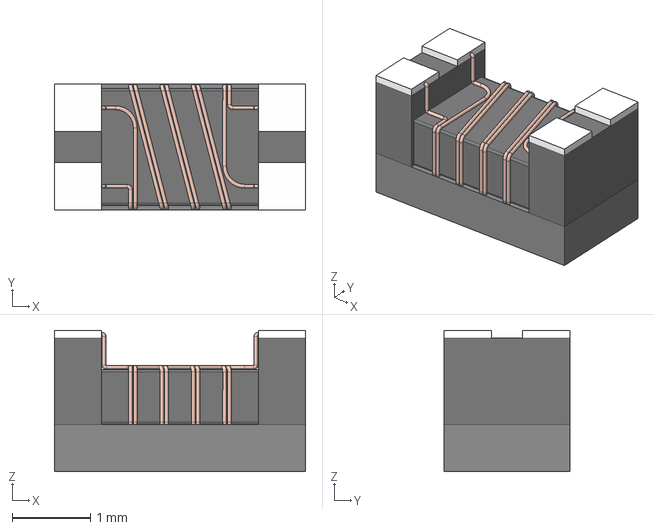
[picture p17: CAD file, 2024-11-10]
HARDWARE/3D MODELS/WE CNSW_1206_CNSW (rev1).igs
3.20 x 1.60 x 1.80 mm

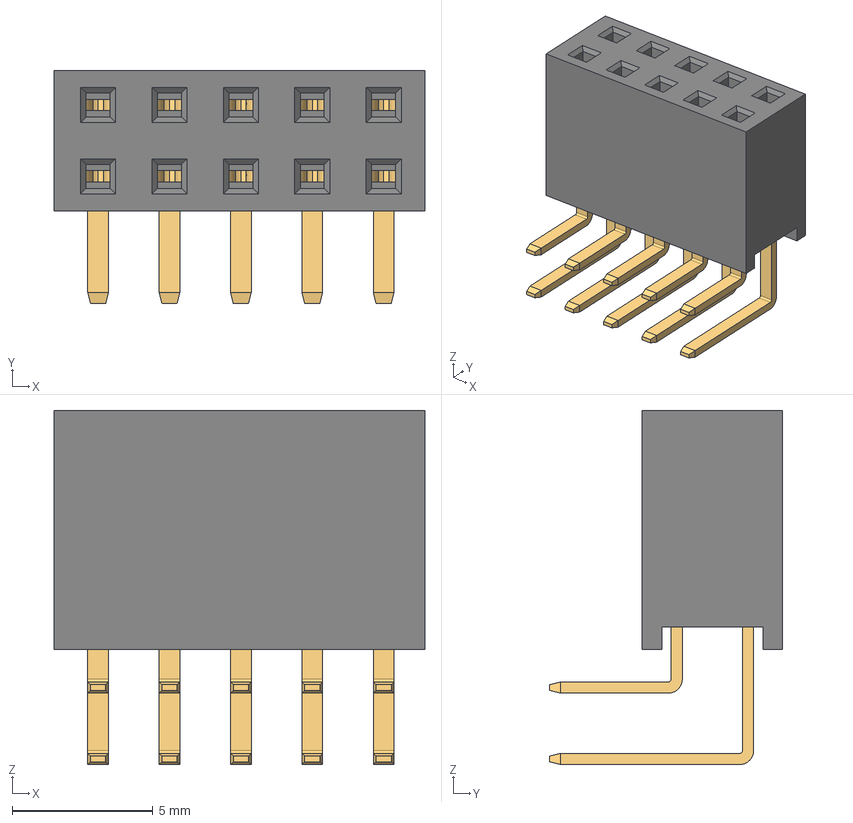
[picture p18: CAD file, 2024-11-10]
HARDWARE/3D MODELS/WE 613010243121 (rev1).iges
13.2 x 8.30 x 12.6 mm

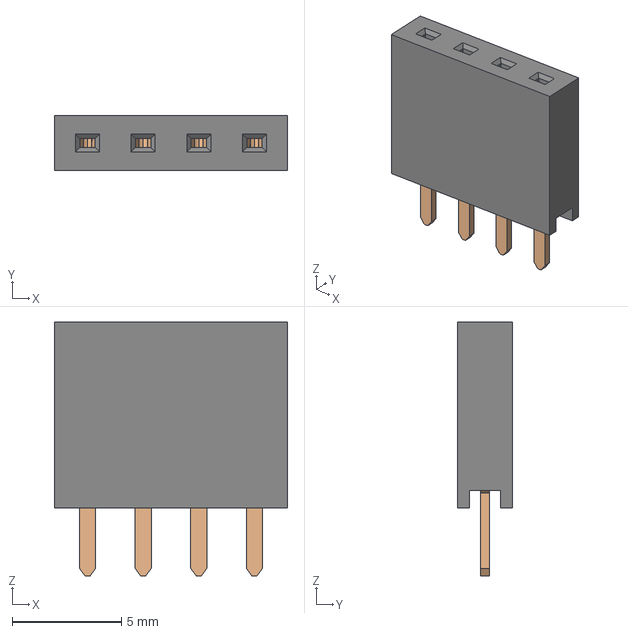
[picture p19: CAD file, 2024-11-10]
HARDWARE/3D MODELS/WE 61300411821 (rev1).iges
10.7 x 2.50 x 11.6 mm

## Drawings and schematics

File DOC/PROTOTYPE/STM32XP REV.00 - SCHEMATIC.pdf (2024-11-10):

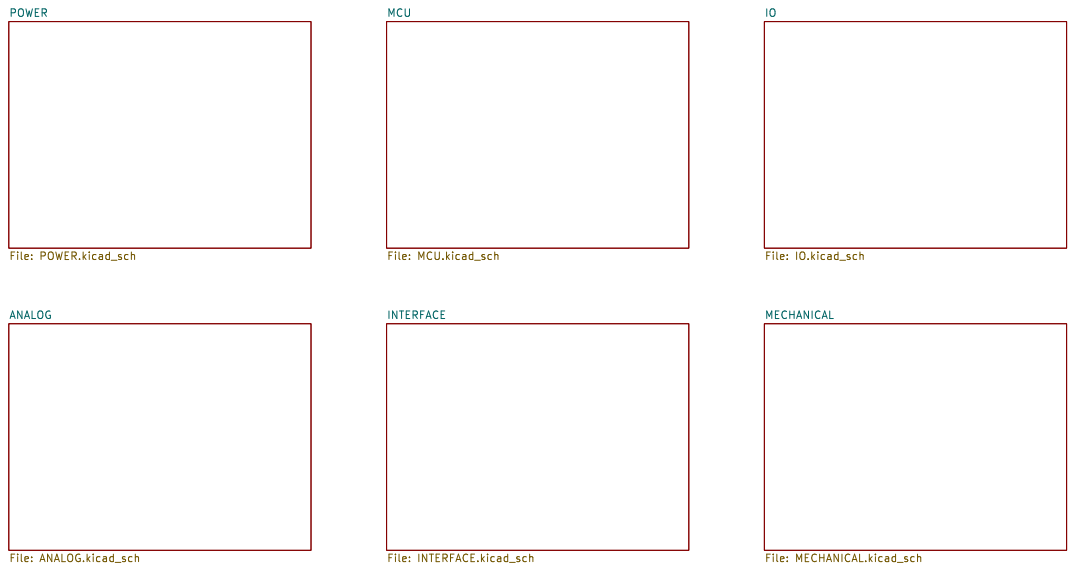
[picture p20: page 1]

MCU
File: IO.kicad_sch MECHANICAL File: MECHANICAL.kicad_sch

Id: 1/7 Title: STM32 EXPLORER BOARD PROTOTYPE

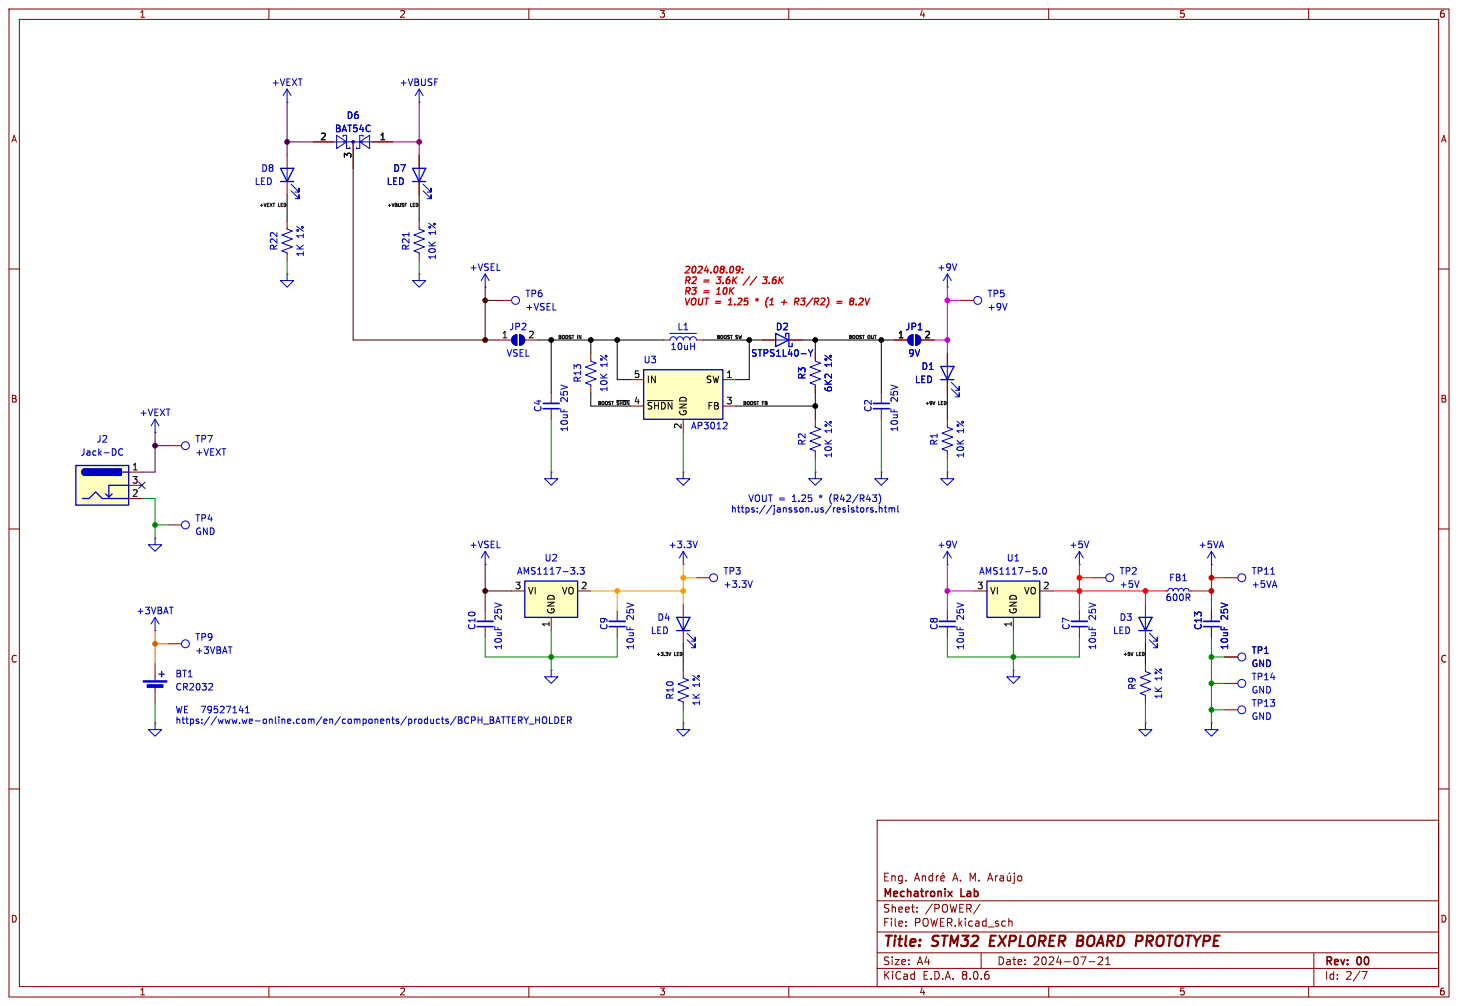
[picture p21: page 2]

https://www.we-online.com/en/components/products/BCPH_BATTERY_HOLDER

Id: 2/7 Title: STM32 EXPLORER BOARD PROTOTYPE

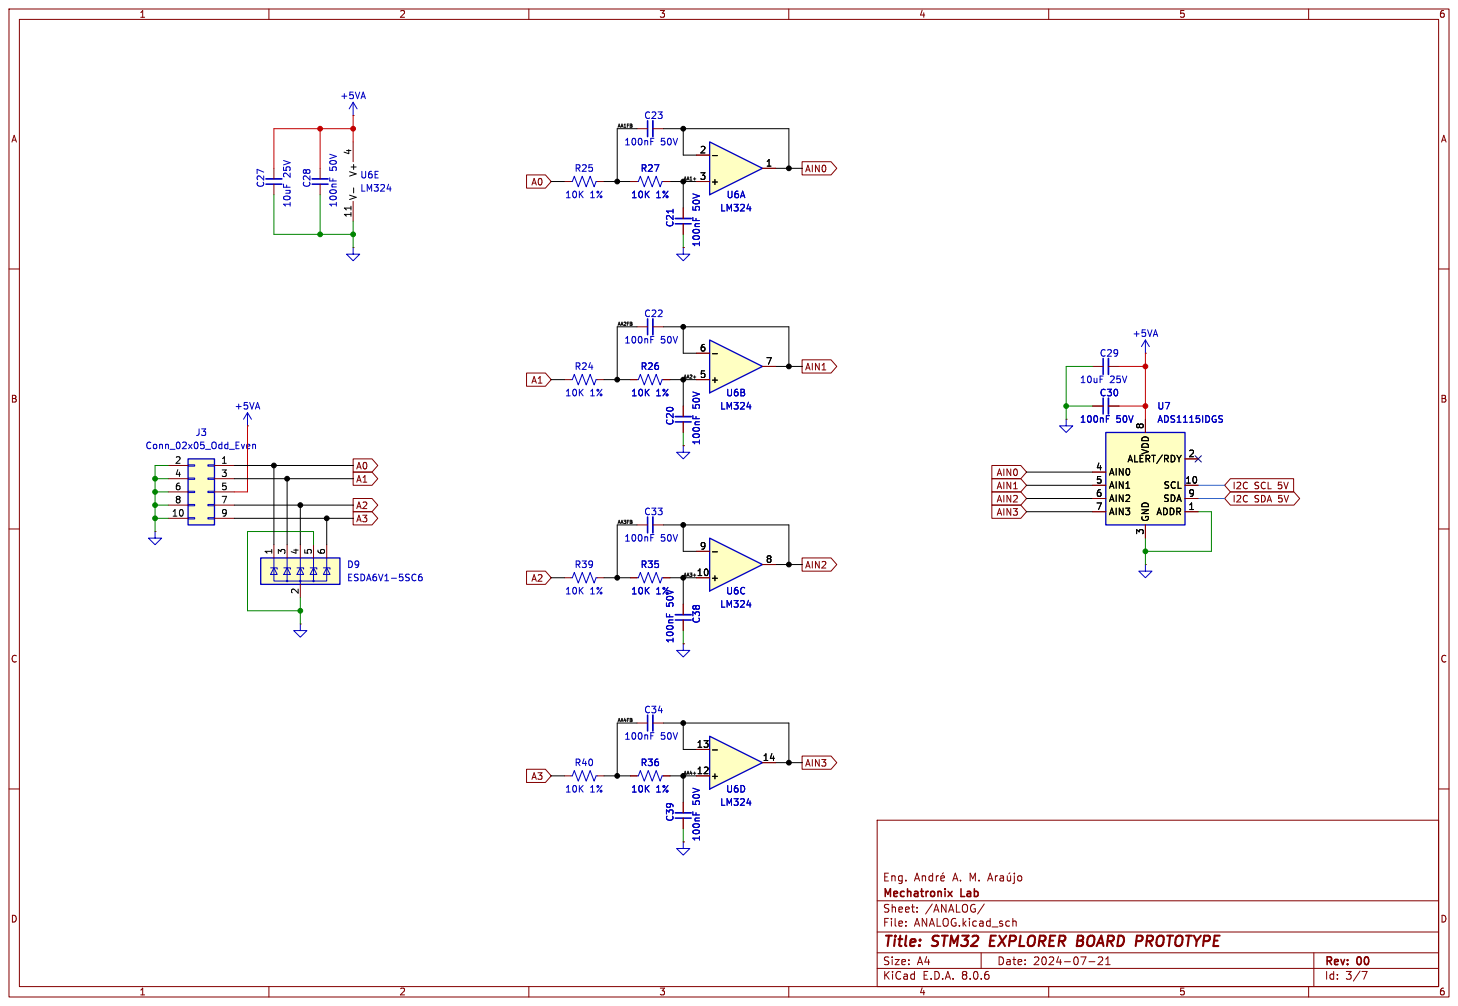
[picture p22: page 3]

Id: 3/7 Title: STM32 EXPLORER BOARD PROTOTYPE

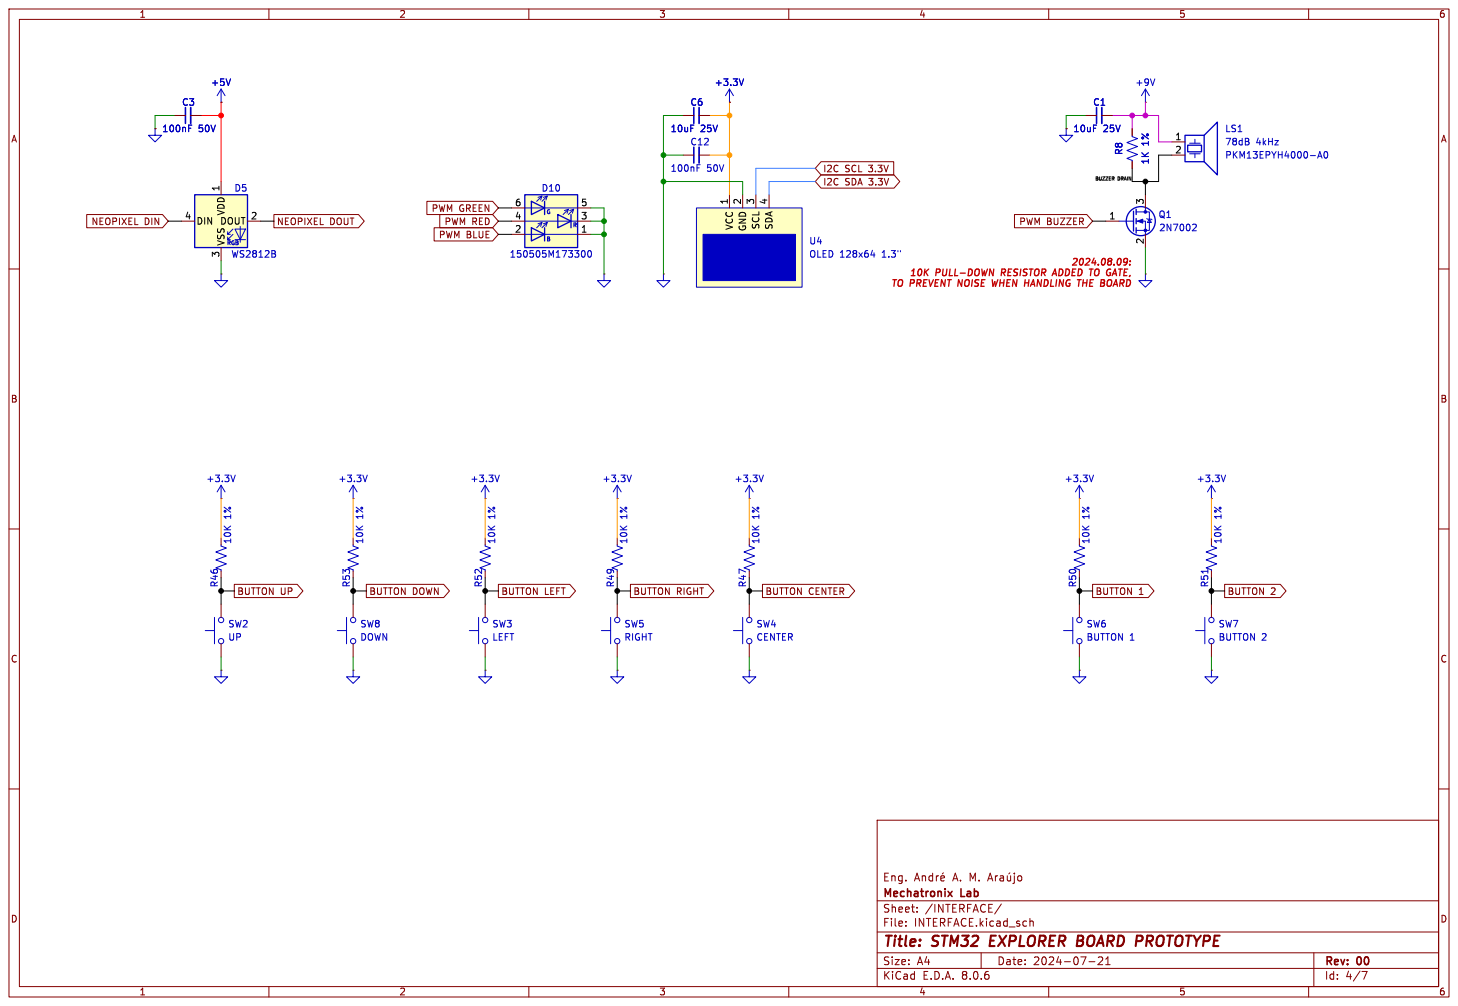
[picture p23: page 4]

Id: 4/7 Title: STM32 EXPLORER BOARD PROTOTYPE

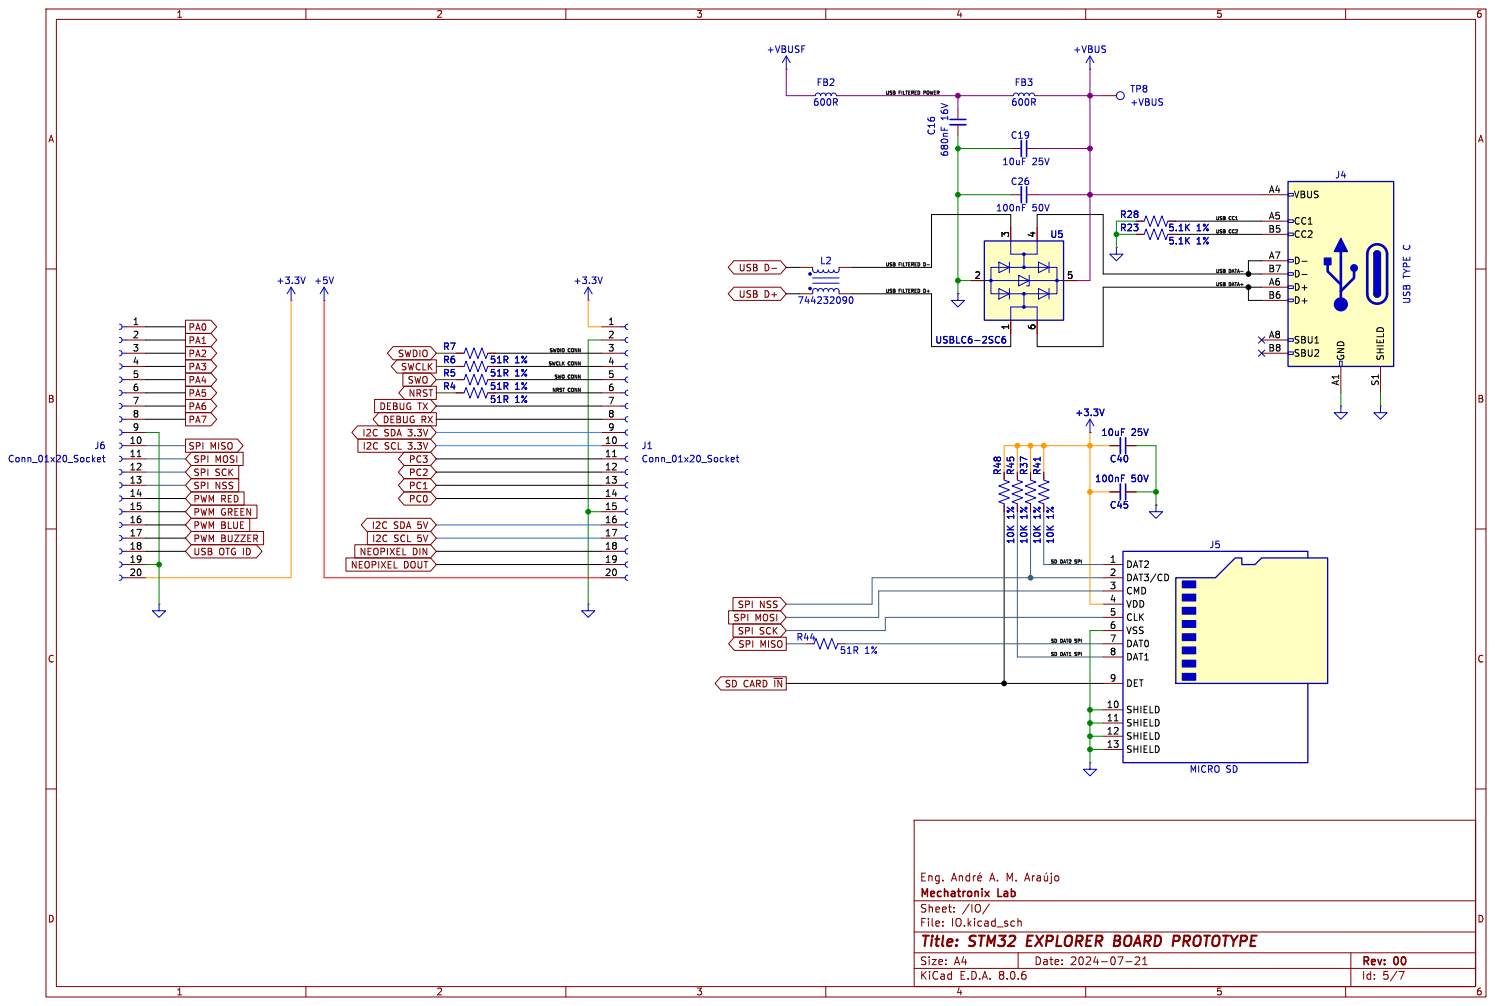
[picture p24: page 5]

+VBUS
TP8 +VBUS R37 10K 1%
USB FILTERED D+ USB FILTERED D- USB FILTERED POWER

USB DATA+ USB CC2 USB CC1 USB DATA- SWCLK CONN
PC0 SWCLK NEOPIXEL DOUT SWDIO

DEBUG RX DEBUG TX

SPI MOSI SPI MISO

SD CARD ~{IN} SPI NSS

Id: 5/7 Title: STM32 EXPLORER BOARD PROTOTYPE

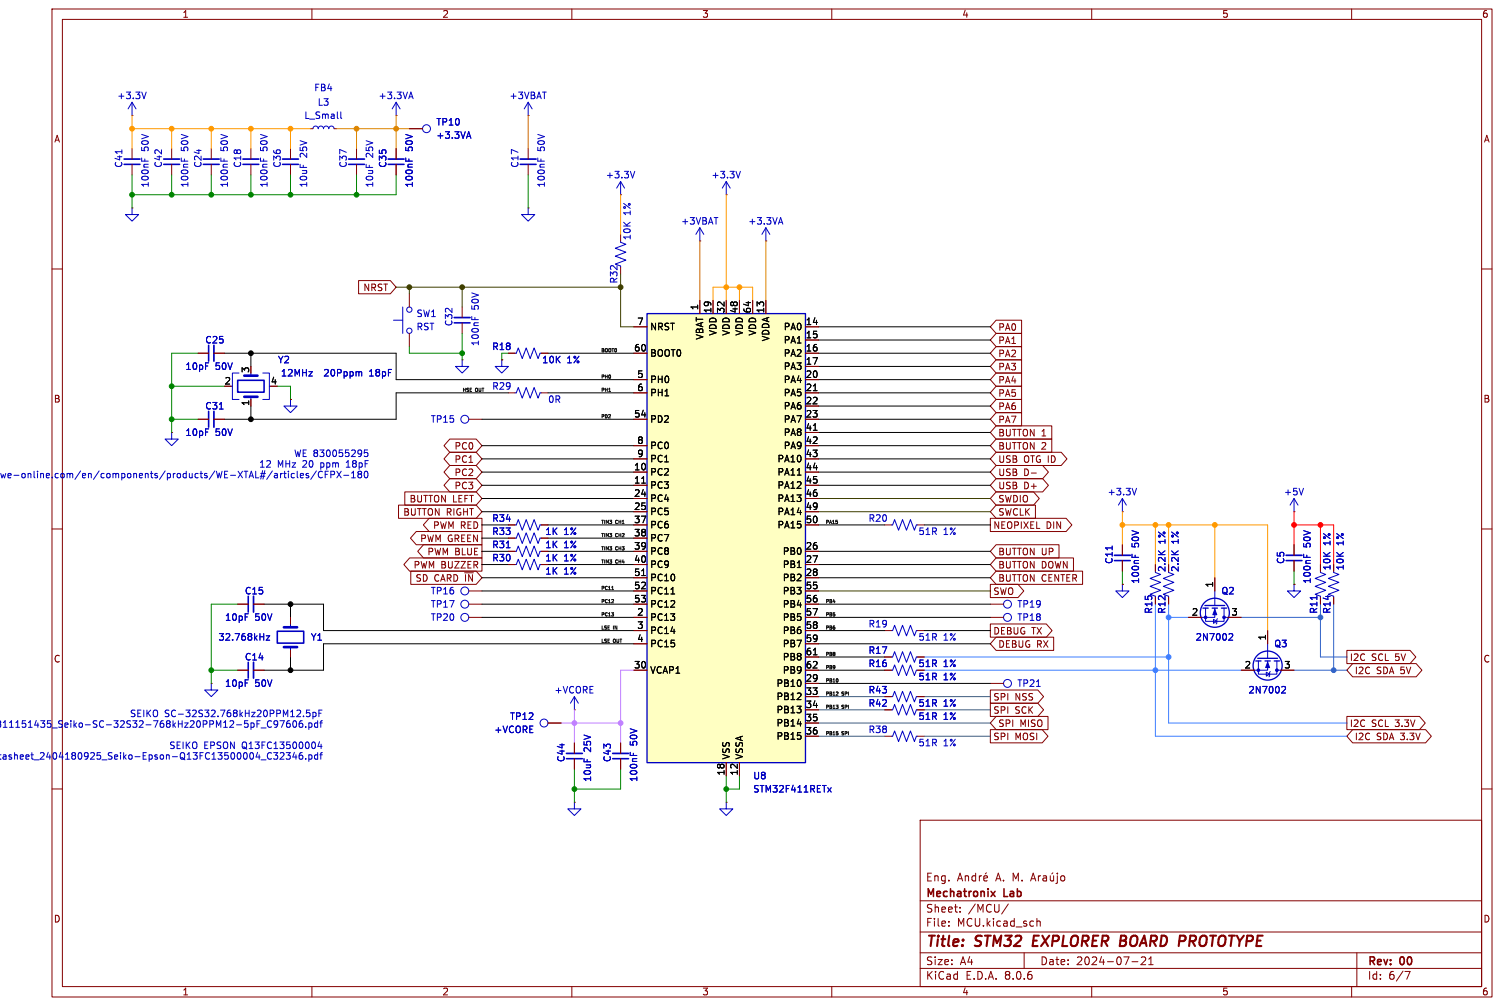
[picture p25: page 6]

1 PC2 10 PC3 11 VSSA 12 VDDA 13 PA0 14 PA1 15 PA2 16 PA3 17 VSS 18 VDD 19 PC13 2 PA4 20 PA5 21 PA6 22 PA7 23 PC4 24 PC5 25 PB0 26 PB1 27 PB2 28 PB10 29 PC14 3 VCAP1 30 VDD 32 PB12 33 PB13 34 PB14 35 PB15 36 PC6 37 PC7 38 PC8 39 PC15 4 PC9 40 PA8 41 PA9 42 PA10 43 PA11 44 PA12 45 PA13 46 VDD 48 PA14 49 PH0 5 PA15 50 PC10 51 PC11 52 PC12 53 PD2 54 PB3 55 PB4 56 PB5 57 PB6 58 PB7 59 PH1 6 BOOT0 60 PB8 61 PB9 62 VDD 64 NRST 7 PC0 8 PC1 9 U8STM32F411RETx

1 PC2 10 PC3 11 VSSA 12 VDDA 13 PA0 14 PA1 15 PA2 16 PA3 17 VSS 18 VDD 19 PC13 2 PA4 20 PA5 21 PA6 22 PA7 23 PC4 24 PC5 25 PB0 26 PB1 27 PB2 28 PB10 29 PC14 3 VCAP1 30 VDD 32 PB12 33 PB13 34 PB14 35 PB15 36 PC6 37 PC7 38 PC8 39 PC15 4 PC9 40 PA8 41 PA9 42 PA10 43 PA11 44 PA12 45 PA13 46 VDD 48 PA14 49 PH0 5 PA15 50 PC10 51 PC11 52 PC12 53 PD2 54 PB3 55 PB4 56 PB5 57 PB6 58 PB7 59 PH1 6 BOOT0 60 PB8 61 PB9 62 VDD 64 NRST 7 PC0 8 PC1 9 Q2

PA0 SPI MISO
PA1 PA2 PA4 SPI SCK
SPI MOSI PA3 BUTTON 1 USB D- USB D+ SWDIO
PA5 DEBUG TX
PA6 BUTTON 2 PA7 DEBUG RX

https://www.we-online.com/en/components/products/WE-XTAL#/articles/CFPX-180 SEIKO SC-32S32.768kHz20PPM12.5pF

https://www.lcsc.com/datasheet/lcsc_datasheet_1811151435_Seiko-SC-32S32-768kHz20PPM12-5pF_C97606.pdf SEIKO EPSON Q13FC13500004

https://www.lcsc.com/datasheet/lcsc_datasheet_2404180925_Seiko-Epson-Q13FC13500004_C32346.pdf

Id: 6/7 Title: STM32 EXPLORER BOARD PROTOTYPE

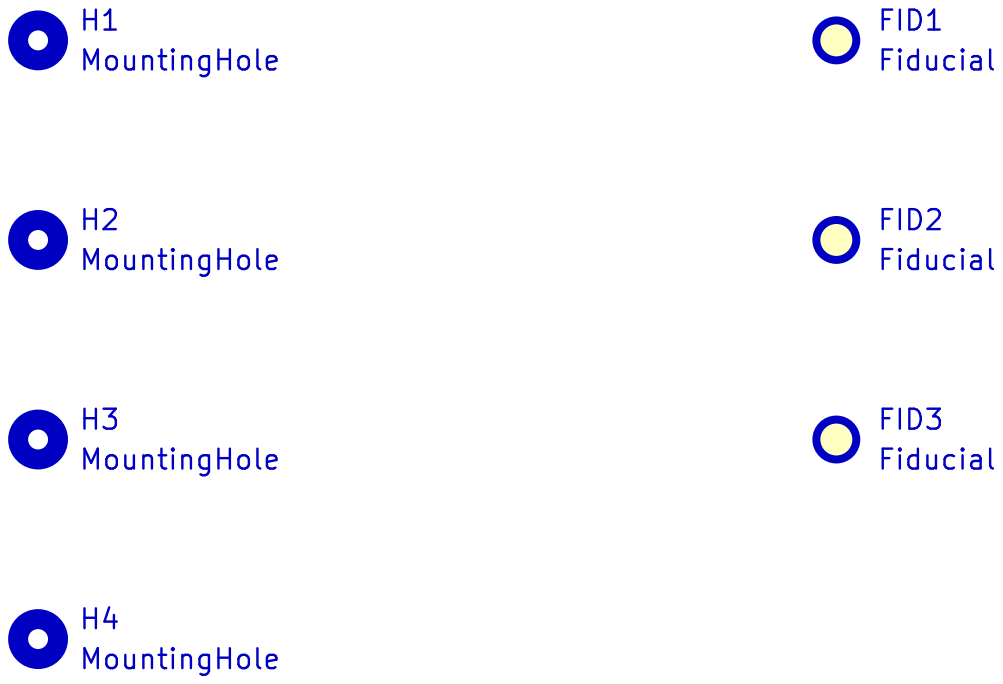
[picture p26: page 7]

Id: 7/7 Title: STM32 EXPLORER BOARD PROTOTYPE

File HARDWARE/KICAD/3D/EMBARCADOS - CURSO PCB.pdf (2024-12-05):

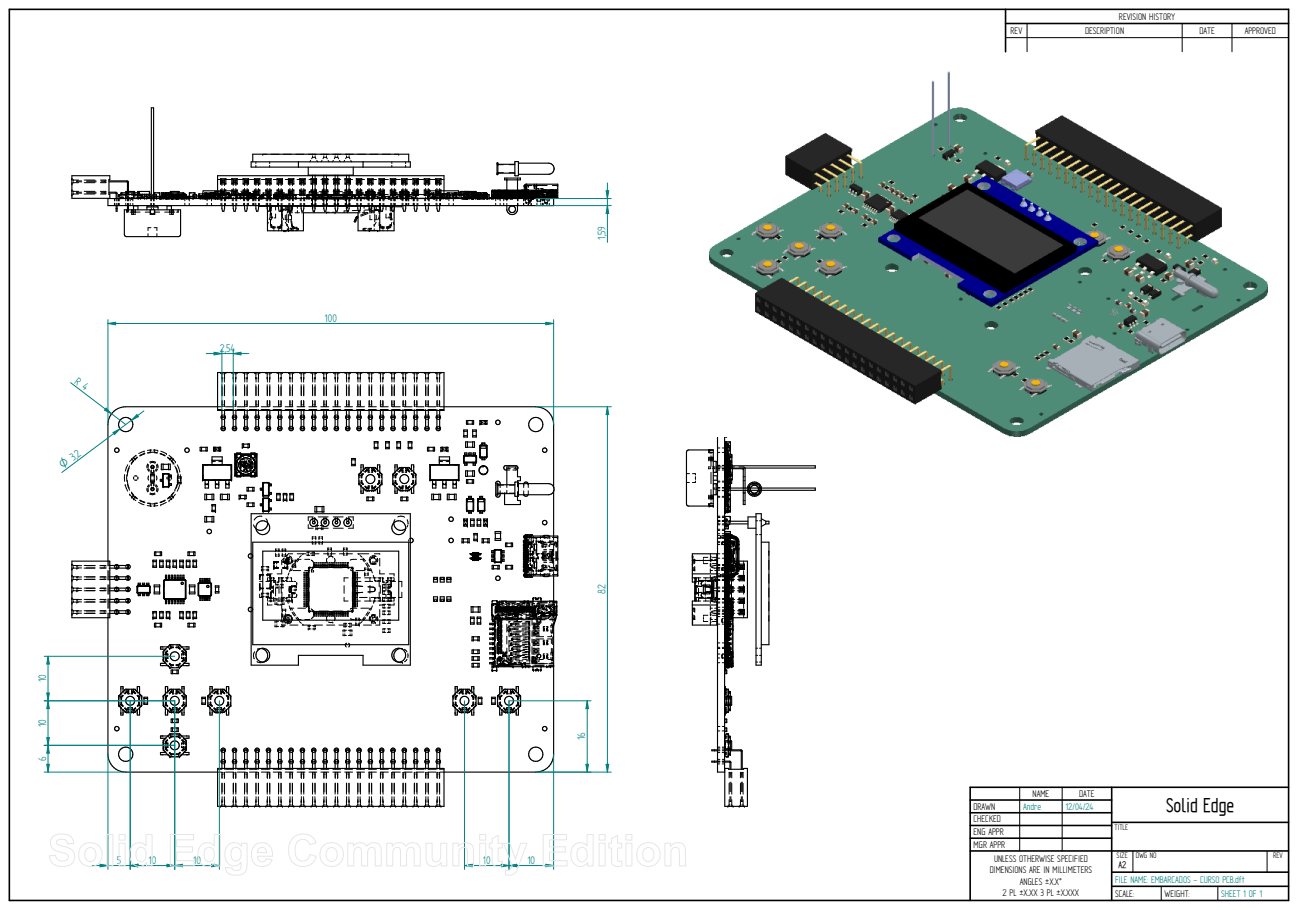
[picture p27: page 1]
TITLE; SCALE:; WEIGHT:; SHEET 1 OF 1

REVISION HISTORY

REV | DESCRIPTION | DATE | APPROVED

NAME | DATE | Solid Edge

DRAWN | Andre | 12/04/24
CHECKED
ENG APPR
MGR APPR
UNLESS OTHERWISE SPECIFIED DIMENSIONS ARE IN MILLIMETERS ANGLES ±X.X° 2 PL ±X.XX 3 PL ±X.XXX | SIZE A2 | DWG NO | REV

FILE NAME: EMBARCADOS - CURSO PCB.dft

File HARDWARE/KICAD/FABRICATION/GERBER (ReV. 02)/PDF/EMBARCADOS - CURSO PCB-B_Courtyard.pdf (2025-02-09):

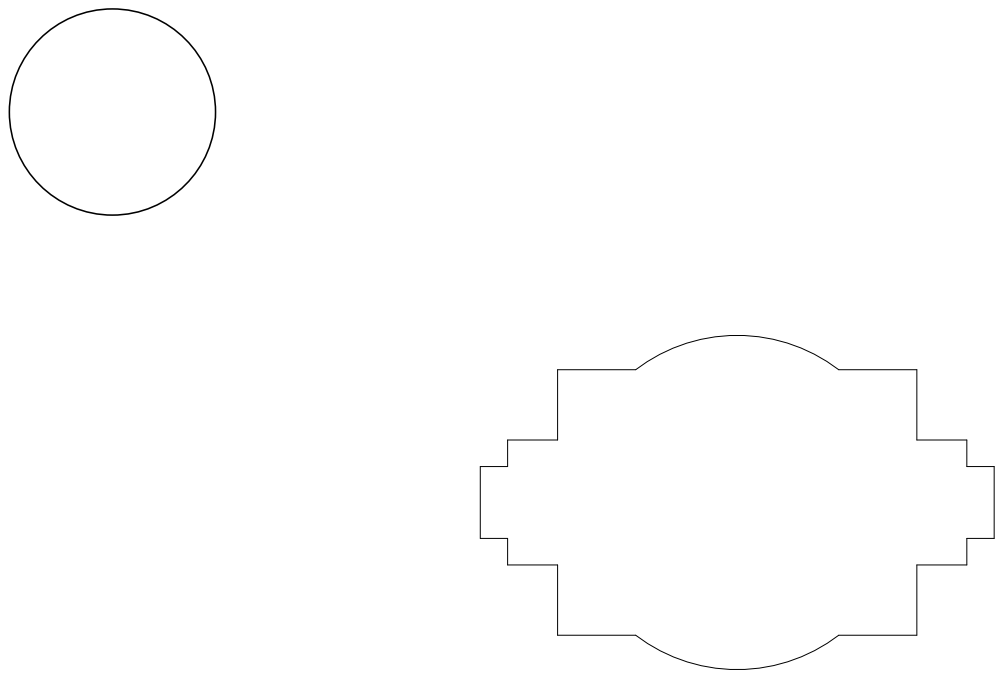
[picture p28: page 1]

Id: 1/1 Title: EMBARCADOS - CURSO PCB

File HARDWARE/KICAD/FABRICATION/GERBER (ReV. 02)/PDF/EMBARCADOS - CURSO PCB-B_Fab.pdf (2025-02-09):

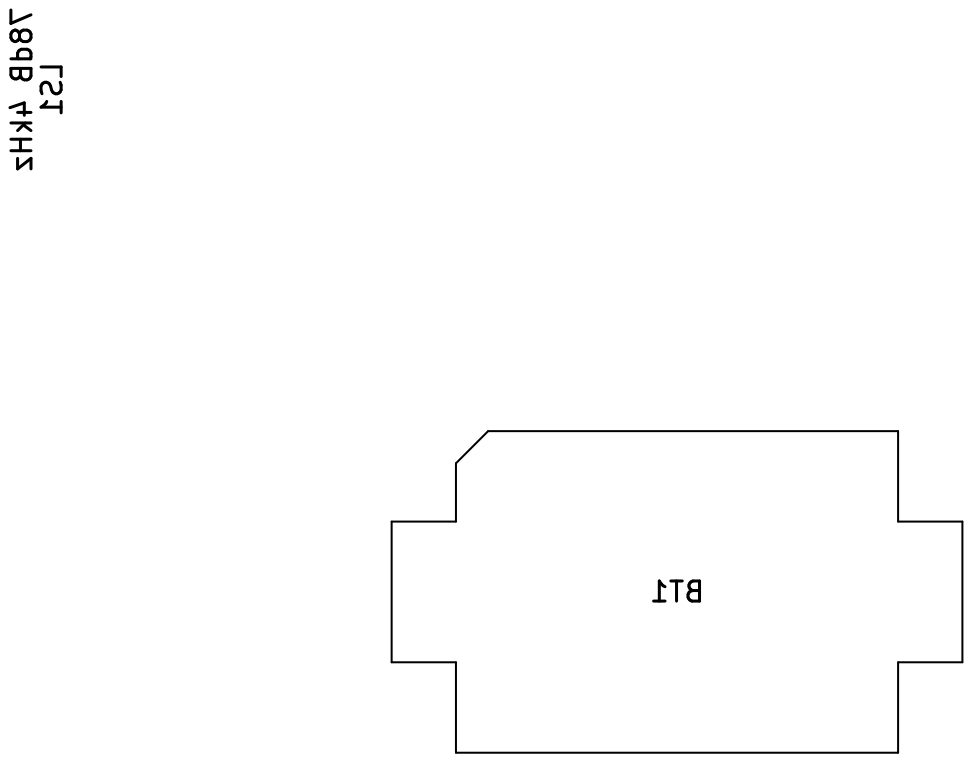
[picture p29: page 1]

Id: 1/1 Title: EMBARCADOS - CURSO PCB

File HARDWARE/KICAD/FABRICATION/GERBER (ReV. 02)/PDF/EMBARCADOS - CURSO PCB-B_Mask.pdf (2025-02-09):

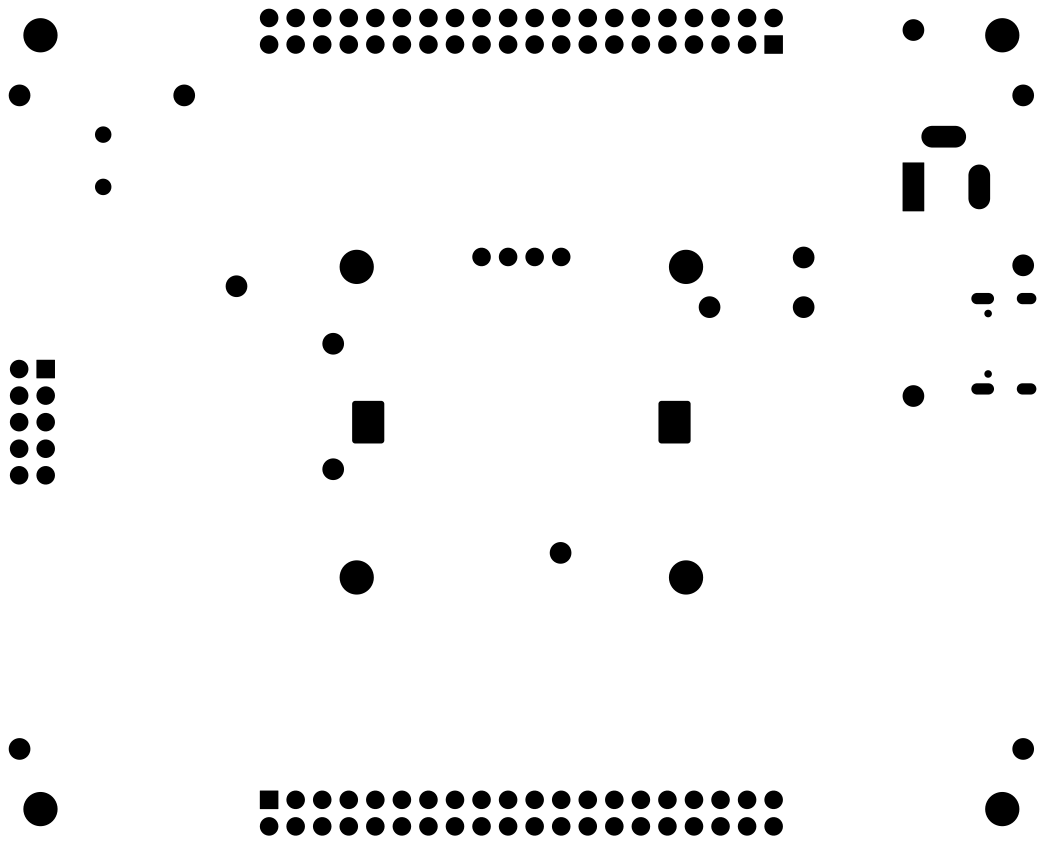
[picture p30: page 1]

Id: 1/1 Title: EMBARCADOS - CURSO PCB

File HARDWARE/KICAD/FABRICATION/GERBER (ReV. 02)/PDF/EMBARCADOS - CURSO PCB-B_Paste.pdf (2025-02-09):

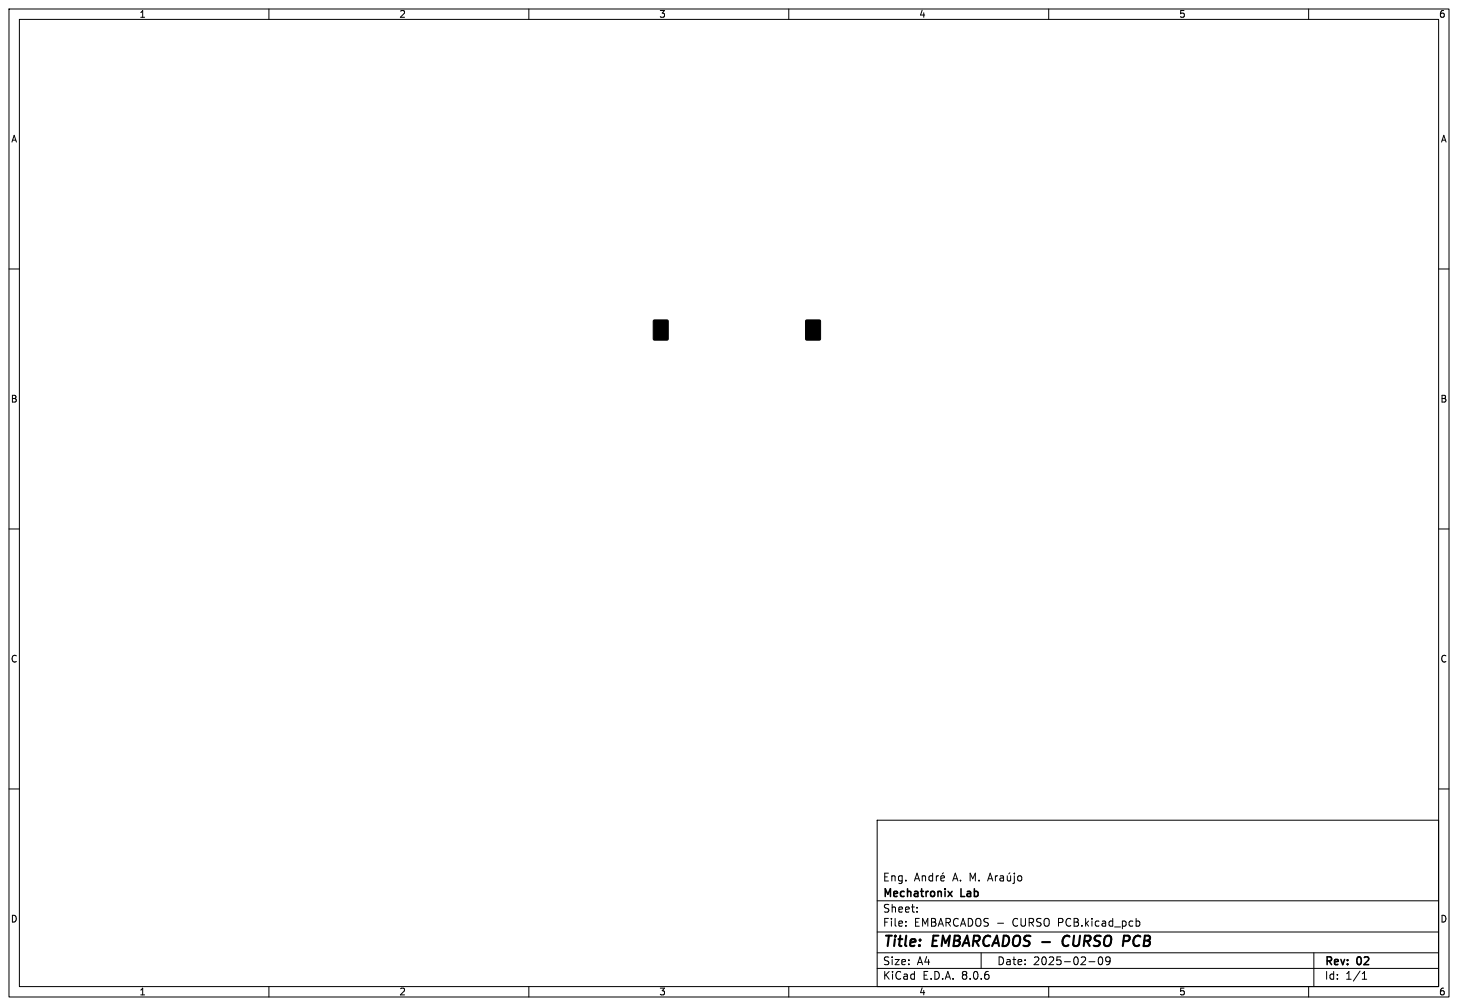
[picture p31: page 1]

Id: 1/1 Title: EMBARCADOS - CURSO PCB

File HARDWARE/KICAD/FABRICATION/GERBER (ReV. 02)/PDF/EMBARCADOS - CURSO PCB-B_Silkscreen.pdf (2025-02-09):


Id: 1/1 Title: EMBARCADOS - CURSO PCB

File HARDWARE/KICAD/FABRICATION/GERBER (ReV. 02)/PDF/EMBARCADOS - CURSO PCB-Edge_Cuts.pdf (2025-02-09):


Id: 1/1 Title: EMBARCADOS - CURSO PCB

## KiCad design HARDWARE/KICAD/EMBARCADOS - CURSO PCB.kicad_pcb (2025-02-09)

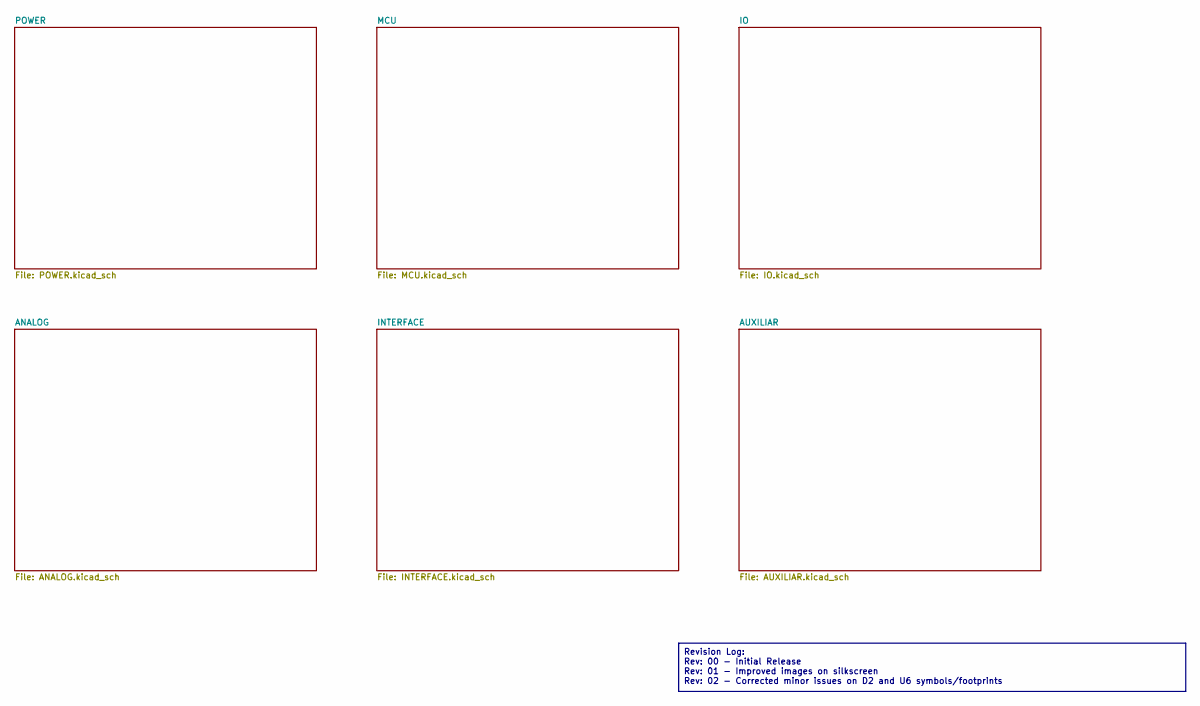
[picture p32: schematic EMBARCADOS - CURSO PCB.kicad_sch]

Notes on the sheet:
Revision Log: Rev: 00 - Initial Release Rev: 01 - Improved images on silkscreen Rev: 02 - Corrected minor issues on D2 and U6 symbols/footprints

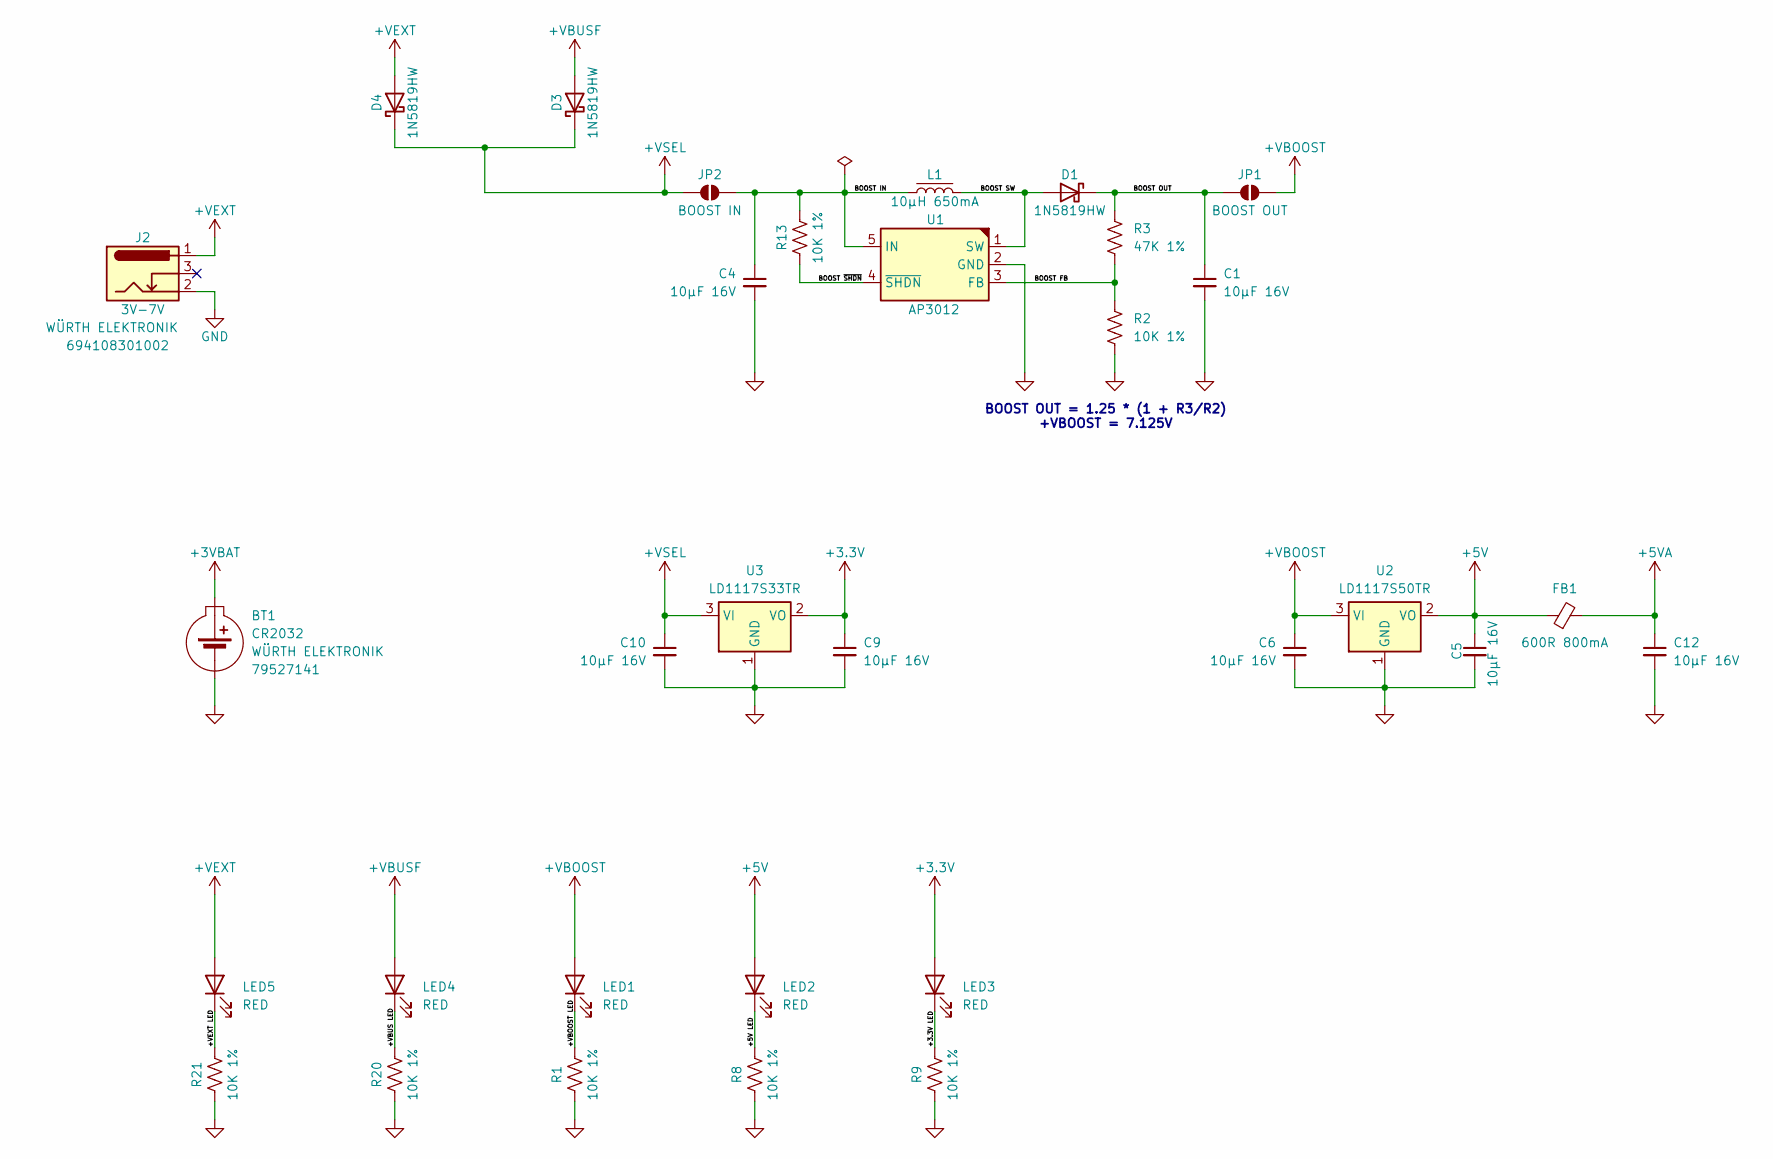
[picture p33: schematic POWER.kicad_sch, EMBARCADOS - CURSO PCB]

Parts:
BT1: CR2032; BatteryHolder_Keystone_1060_1x2032; MPN 79527141
C1, C4, C5, C6, C9, C10, C12: 10µF 16V; C_0805_2012Metric; MPN KGM21AR71C106K; LCSC MPN CL21A106KAYNNNE
D1, D3, D4: 1N5819HW; D_SOD-123; MPN 1N5819HW-7-F; LCSC Part # C82544
FB1: 600R 800mA; L_0603_1608Metric; MPN 742792651; LCSC Part # C963865
J2: 3V-7V; BarrelJack_GCT_DCJ200-10-A_Horizontal; MPN 694108301002
JP1: BOOST OUT; SolderJumper-2_P1.3mm_Open_RoundedPad1.0x1.5mm
JP2: BOOST IN; SolderJumper-2_P1.3mm_Open_RoundedPad1.0x1.5mm
L1: 10µH 650mA; WE-LQS SMT Semi-Shielded Power Inductor; MPN 74404024100; LCSC Part # C520138
LED1, LED2, LED3, LED4, LED5: RED; LED_0603_1608Metric; MPN 150060SS55040; LCSC Part # C128052
R1, R2, R8, R9, R13, R20, R21: 10K 1%; R_0603_1608Metric; MPN CRCW060310K0FK; LCSC Part # C25804
R3: 47K 1%; R_0603_1608Metric; MPN CRCW060347K0FK; LCSC Part # C25819
U1: AP3012; SOT-23-5; MPN AP3012KTR-E1; LCSC Part # C460356
U2: LD1117S50TR; SOT-223-3_TabPin2; MPN LD1117S50TR; LCSC Part # C6187
U3: LD1117S33TR; SOT-223-3_TabPin2; MPN LD1117S33TR; LCSC Part # C6186

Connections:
+3.3V: C9.1, LED3.2 (A), U3.2 (VO); also elsewhere on the board
+3VBAT: BT1.1 (+); also elsewhere on the board
+5V: C5.1, FB1.1, LED2.2 (A), U2.2 (VO); also elsewhere on the board
+5VA: C12.1, FB1.2; also elsewhere on the board
+VBOOST: C6.1, JP1.2 (B), LED1.2 (A), U2.3 (VI); also elsewhere on the board
+VBUSF: D3.2 (A), LED4.2 (A); also elsewhere on the board
+VEXT: D4.2 (A), J2.1, LED5.2 (A); also elsewhere on the board
+VSEL: C10.1, D3.1 (K), D4.1 (K), JP2.1 (A), U3.3 (VI); also elsewhere on the board
/POWER/+3.3V LED: LED3.1 (K), R9.2
/POWER/+5V LED: LED2.1 (K), R8.2
/POWER/+VBOOST LED: LED1.1 (K), R1.2
/POWER/+VBUS LED: LED4.1 (K), R20.2
/POWER/+VEXT LED: LED5.1 (K), R21.2
/POWER/BOOST FB: R2.1, R3.2, U1.3 (FB)
/POWER/BOOST IN: C4.1, JP2.2 (B), L1.1, R13.2, U1.5 (IN)
/POWER/BOOST OUT: C1.1, D1.1 (K), JP1.1 (A), R3.1
/POWER/BOOST SW: D1.2 (A), L1.2, U1.1 (SW)
/POWER/BOOST ~SHDN: R13.1, U1.4 (~SHDN)
GND: BT1.2 (-), C1.2, C4.2, C5.2, C6.2, C9.2, C10.2, C12.2, J2.2, R1.1, R2.2, R8.1, R9.1, R20.1, R21.1, U1.2 (GND), U2.1 (GND), U3.1 (GND); also elsewhere on the board

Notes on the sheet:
BOOST OUT = 1.25 * (1 + R3/R2) +VBOOST = 7.125V

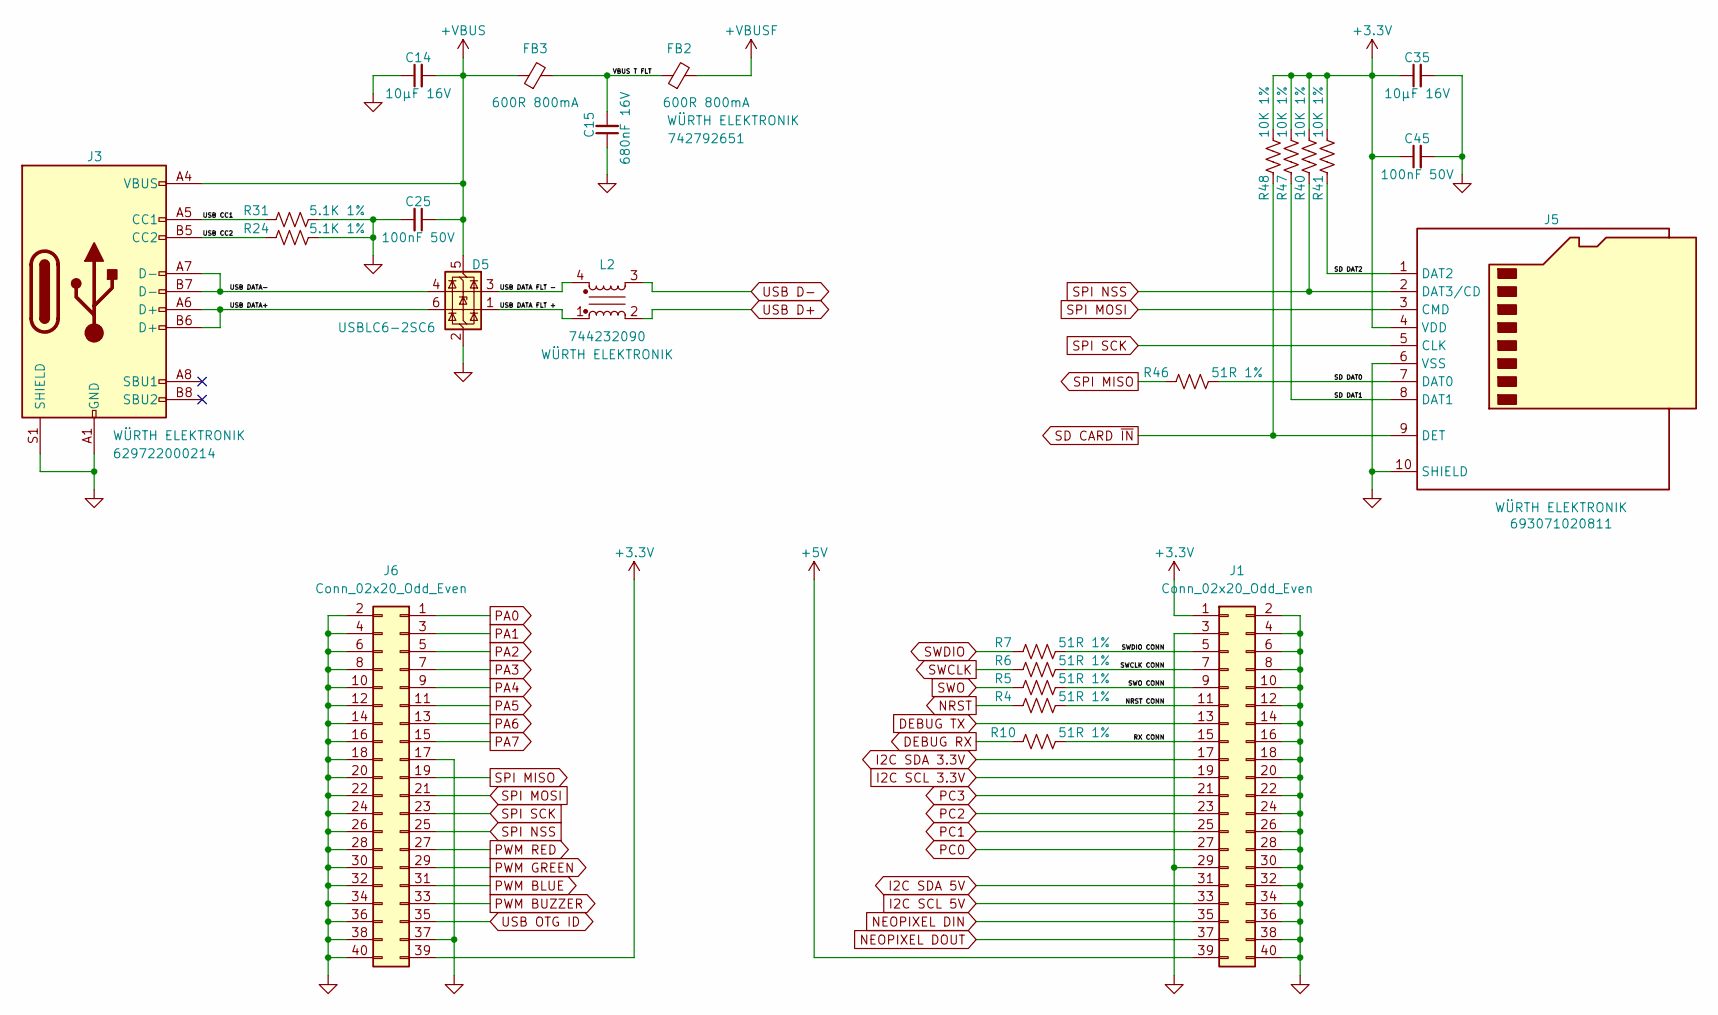
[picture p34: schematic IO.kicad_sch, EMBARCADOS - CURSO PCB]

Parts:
C14, C35: 10µF 16V; C_0805_2012Metric; MPN KGM21AR71C106K; LCSC MPN CL21A106KAYNNNE
C15: 680nF 16V; C_0603_1608Metric; MPN KGM15BR71C684M; LCSC MPN CC0603KRX5R8BB684
C25, C45: 100nF 50V; C_0603_1608Metric; MPN KGM15BR71H104K; LCSC MPN CC0603KRX7R9BB104
D5: USBLC6-2SC6; SOT-23-6; MPN USBLC6-2SC6; LCSC Part # C2827654
FB2, FB3: 600R 800mA; L_0603_1608Metric; MPN 742792651; LCSC Part # C963865
J1, J6: Conn_02x20_Odd_Even; PinSocket_2x20_P2.54mm_Horizontal; MPN 613040243121
J3: USB; USB_C_Receptacle_G-Switch_GT-USB-7010ASV; MPN 629722000214; LCSC Part # C2927038
J5: Micro SD; WE 693071020811; MPN 693071020811; LCSC Part # C19189038
L2: USB 2.0; WE-CNSW SMT Common Mode Line Filter; MPN 744232090
R4, R5, R6, R7, R10, R46: 51R 1%; R_0603_1608Metric; MPN CRCW060351R0FK; LCSC Part # C23197
R24, R31: 5.1K 1%; R_0603_1608Metric; MPN CRCW06035K10FK; LCSC Part # C23186
R40, R41, R47, R48: 10K 1%; R_0603_1608Metric; MPN CRCW060310K0FK; LCSC Part # C25804

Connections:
+3.3V: C35.1, C45.1, J1.1, J5.4 (VDD), J6.39, R40.1, R41.1, R47.1, R48.1; also elsewhere on the board
+5V: J1.39; also elsewhere on the board
+VBUS: C14.2, C25.1, D5.5 (VBUS), FB3.1, J3.A4 (VBUS), J3.A9 (VBUS), J3.B4 (VBUS), J3.B9 (VBUS); also elsewhere on the board
+VBUSF: FB2.2; also elsewhere on the board
/IO/NRST CONN: J1.11, R4.2
/IO/RX CONN: J1.15, R10.2
/IO/SD DAT0: J5.7 (DAT0), R46.2
/IO/SD DAT1: J5.8 (DAT1), R47.2
/IO/SD DAT2: J5.1 (DAT2), R41.2
/IO/SWCLK CONN: J1.7, R6.2
/IO/SWDIO CONN: J1.5, R7.2
/IO/SWO CONN: J1.9, R5.2
/IO/USB CC1: J3.A5 (CC1), R31.1
/IO/USB CC2: J3.B5 (CC2), R24.1
/IO/USB DATA FLT +: D5.1 (I/O1), L2.1
/IO/USB DATA FLT -: D5.3 (I/O2), L2.4
/IO/USB DATA+: D5.6 (I/O1), J3.A6 (D+), J3.B6 (D+)
/IO/USB DATA-: D5.4 (I/O2), J3.A7 (D-), J3.B7 (D-)
/IO/VBUS T FLT: C15.2, FB2.1, FB3.2
DEBUG RX: R10.1; also elsewhere on the board
DEBUG TX: J1.13; also elsewhere on the board
GND: C14.1, C15.1, C25.2, C35.2, C45.2, D5.2 (GND), J1.2, J1.3, J1.4, J1.6, J1.8, J1.10, J1.12, J1.14, J1.16, J1.18, J1.20, J1.22, J1.24, J1.26, J1.28, J1.29, J1.30, J1.32, J1.34, J1.36, J1.38, J1.40, J3.A1 (GND), J3.A12 (GND), J3.B1 (GND), J3.B12 (GND), J3.S1 (SHIELD), J5.6 (VSS), J5.10 (SHIELD), J5.11 (SHIELD), J5.12 (SHIELD), J5.13 (SHIELD), J6.2, J6.4, J6.6, J6.8, J6.10, J6.12, J6.14, J6.16, J6.17, J6.18, J6.20, J6.22, J6.24, J6.26, J6.28, J6.30, J6.32, J6.34, J6.36, J6.37, J6.38, J6.40, R24.2, R31.2; also elsewhere on the board
I2C SCL 3.3V: J1.19; also elsewhere on the board
I2C SCL 5V: J1.33; also elsewhere on the board
I2C SDA 3.3V: J1.17; also elsewhere on the board
I2C SDA 5V: J1.31; also elsewhere on the board
NEOPIXEL DIN: J1.35; also elsewhere on the board
NEOPIXEL DOUT: J1.37; also elsewhere on the board
NRST: R4.1; also elsewhere on the board
PA0: J6.1; also elsewhere on the board
PA1: J6.3; also elsewhere on the board
PA2: J6.5; also elsewhere on the board
PA3: J6.7; also elsewhere on the board
PA4: J6.9; also elsewhere on the board
PA5: J6.11; also elsewhere on the board
PA6: J6.13; also elsewhere on the board
PA7: J6.15; also elsewhere on the board
PC0: J1.27; also elsewhere on the board
PC1: J1.25; also elsewhere on the board
PC2: J1.23; also elsewhere on the board
PC3: J1.21; also elsewhere on the board
PWM BLUE: J6.31; also elsewhere on the board
PWM BUZZER: J6.33; also elsewhere on the board
PWM GREEN: J6.29; also elsewhere on the board
PWM RED: J6.27; also elsewhere on the board
SD CARD ~IN: J5.9 (DET), R48.2; also elsewhere on the board
SPI MISO: J6.19, R46.1; also elsewhere on the board
SPI MOSI: J5.3 (CMD), J6.21; also elsewhere on the board
SPI NSS: J5.2 (DAT3/CD), J6.25, R40.2; also elsewhere on the board
SPI SCK: J5.5 (CLK), J6.23; also elsewhere on the board
SWCLK: R6.1; also elsewhere on the board
SWDIO: R7.1; also elsewhere on the board
SWO: R5.1; also elsewhere on the board
USB D+: L2.2; also elsewhere on the board
USB D-: L2.3; also elsewhere on the board
USB OTG ID: J6.35; also elsewhere on the board

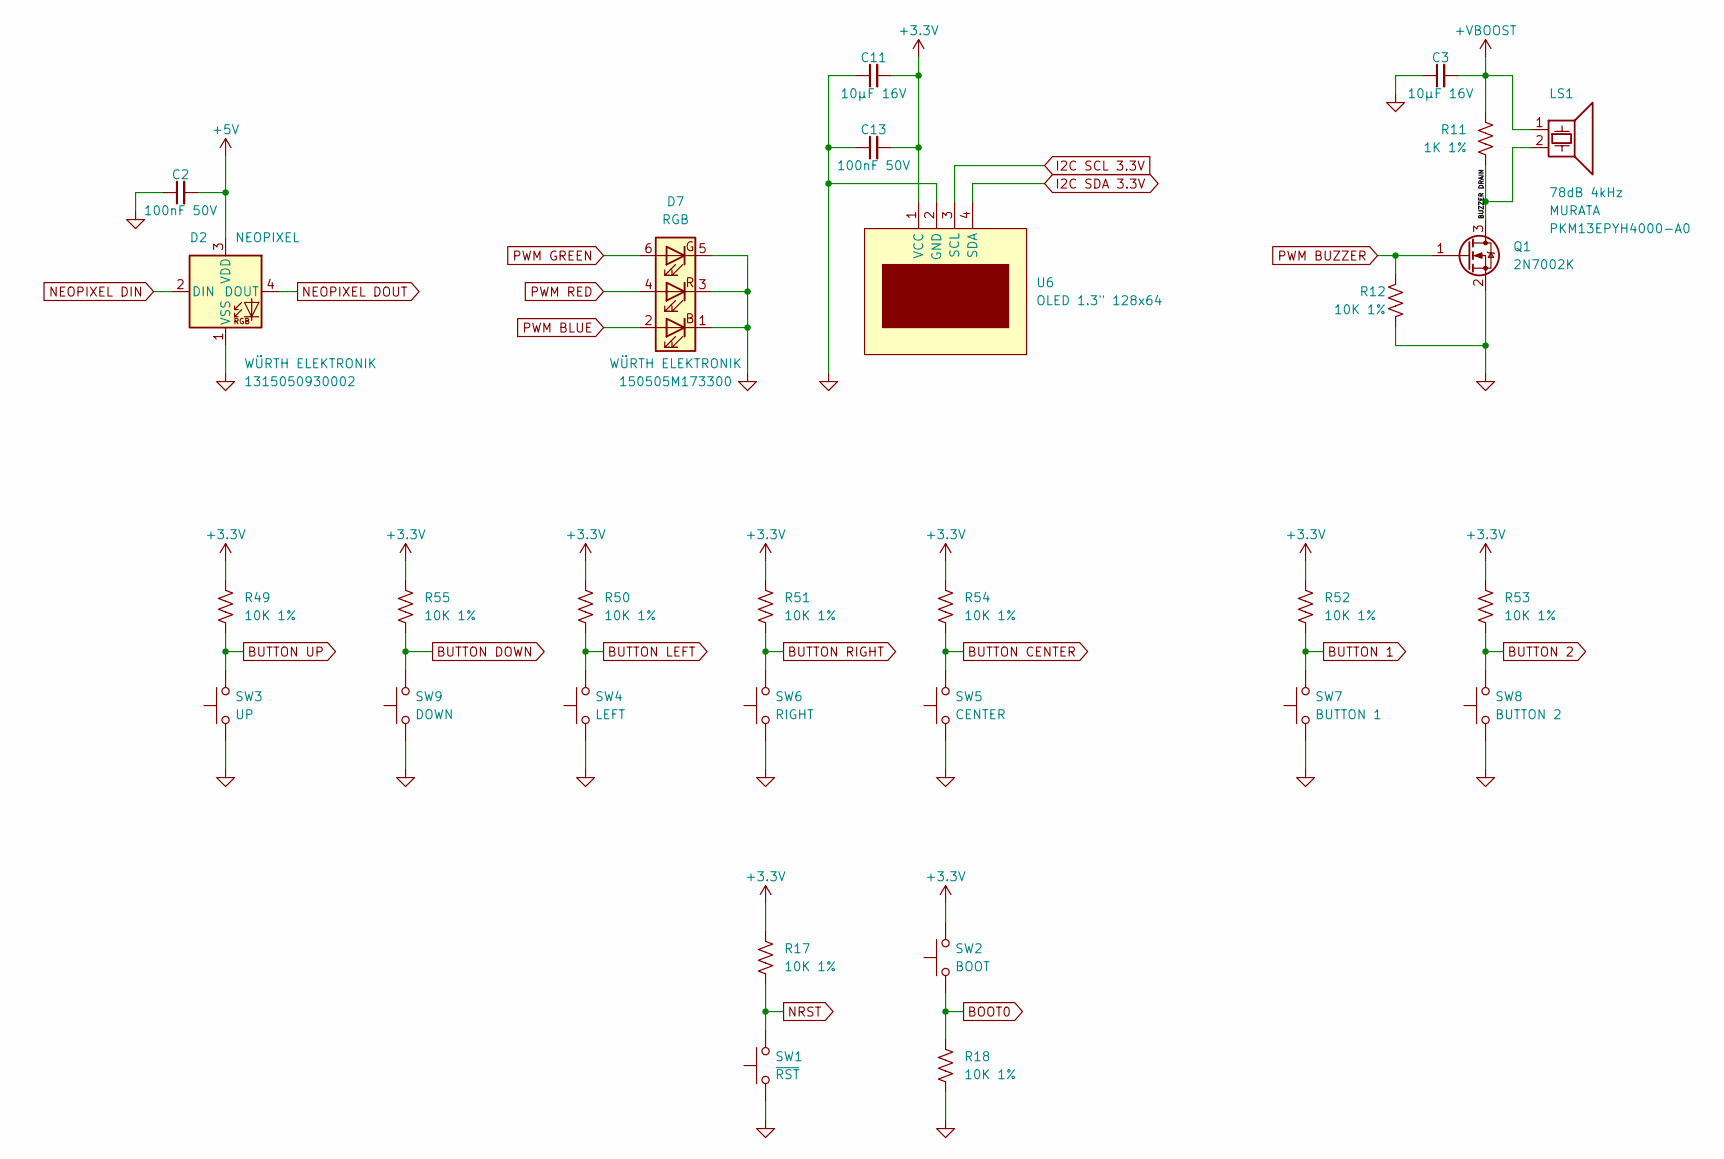
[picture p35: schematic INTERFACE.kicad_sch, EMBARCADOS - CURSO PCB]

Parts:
C2, C13: 100nF 50V; C_0603_1608Metric; MPN KGM15BR71H104K; LCSC MPN CC0603KRX7R9BB104
C3, C11: 10µF 16V; C_0805_2012Metric; MPN KGM21AR71C106K; LCSC MPN CL21A106KAYNNNE
D2: NEOPIXEL; LED_WS2812B_PLCC4_5.0x5.0mm_P3.2mm; MPN 1315050930002
D7: RGB; LED_Inolux_IN-P55TATRGB_PLCC6_5.0x5.5mm_P1.8mm; MPN 150505M173300
LS1: 78dB 4kHz; PKM13EPYH4000-A0; MPN PKM13EPYH4000-A0
Q1: 2N7002K; SOT-23; MPN 2N7002K-7; LCSC Part # C8545
R11: 1K 1%; R_0603_1608Metric; MPN CRCW06031K00FK; LCSC Part # C21190
R12, R17, R18, R49, R50, R51, R52, R53, R54, R55: 10K 1%; R_0603_1608Metric; MPN CRCW060310K0FK; LCSC Part # C25804
SW1: ~{RST}; C&K PTS526SM20SMTR21 LFS; MPN PTS526SM20SMTR21 LFS; LCSC Part # C318884
SW2: BOOT; C&K PTS526SM20SMTR21 LFS; MPN PTS526SM20SMTR21 LFS; LCSC Part # C318884
SW3: UP; C&K PTS526SM20SMTR21 LFS; MPN PTS526SM20SMTR21 LFS; LCSC Part # C318884
SW4: LEFT; C&K PTS526SM20SMTR21 LFS; MPN PTS526SM20SMTR21 LFS; LCSC Part # C318884
SW5: CENTER; C&K PTS526SM20SMTR21 LFS; MPN PTS526SM20SMTR21 LFS; LCSC Part # C318884
SW6: RIGHT; C&K PTS526SM20SMTR21 LFS; MPN PTS526SM20SMTR21 LFS; LCSC Part # C318884
SW7: BUTTON 1; C&K PTS526SM20SMTR21 LFS; MPN PTS526SM20SMTR21 LFS; LCSC Part # C318884
SW8: BUTTON 2; C&K PTS526SM20SMTR21 LFS; MPN PTS526SM20SMTR21 LFS; LCSC Part # C318884
SW9: DOWN; C&K PTS526SM20SMTR21 LFS; MPN PTS526SM20SMTR21 LFS; LCSC Part # C318884
U6: OLED 1.3" 128x64; OLED 128x64 1.3in; MPN 61300411821

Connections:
+3.3V: C11.2, C13.2, R17.1, R49.1, R50.1, R51.1, R52.1, R53.1, R54.1, R55.1, SW2.2 (B), U6.1 (VCC); also elsewhere on the board
+5V: C2.2, D2.3 (VDD); also elsewhere on the board
+VBOOST: C3.2, LS1.1, R11.1; also elsewhere on the board
/INTERFACE/BUZZER DRAIN: LS1.2, Q1.3 (D), R11.2
BOOT0: R18.1, SW2.1 (A); also elsewhere on the board
BUTTON 1: R52.2, SW7.2 (B); also elsewhere on the board
BUTTON 2: R53.2, SW8.2 (B); also elsewhere on the board
BUTTON CENTER: R54.2, SW5.2 (B); also elsewhere on the board
BUTTON DOWN: R55.2, SW9.2 (B); also elsewhere on the board
BUTTON LEFT: R50.2, SW4.2 (B); also elsewhere on the board
BUTTON RIGHT: R51.2, SW6.2 (B); also elsewhere on the board
BUTTON UP: R49.2, SW3.2 (B); also elsewhere on the board
GND: C2.1, C3.1, C11.1, C13.1, D2.1 (VSS), D7.1 (RK), D7.3 (BK), D7.5 (GA), Q1.2 (S), R12.2, R18.2, SW1.1 (A), SW3.1 (A), SW4.1 (A), SW5.1 (A), SW6.1 (A), SW7.1 (A), SW8.1 (A), SW9.1 (A), U6.2 (GND); also elsewhere on the board
I2C SCL 3.3V: U6.3 (SCL); also elsewhere on the board
I2C SDA 3.3V: U6.4 (SDA); also elsewhere on the board
NEOPIXEL DIN: D2.2 (DIN); also elsewhere on the board
NEOPIXEL DOUT: D2.4 (DOUT); also elsewhere on the board
NRST: R17.2, SW1.2 (B); also elsewhere on the board
PWM BLUE: D7.2 (GK); also elsewhere on the board
PWM BUZZER: Q1.1 (G), R12.1; also elsewhere on the board
PWM GREEN: D7.6 (RA); also elsewhere on the board
PWM RED: D7.4 (BA); also elsewhere on the board

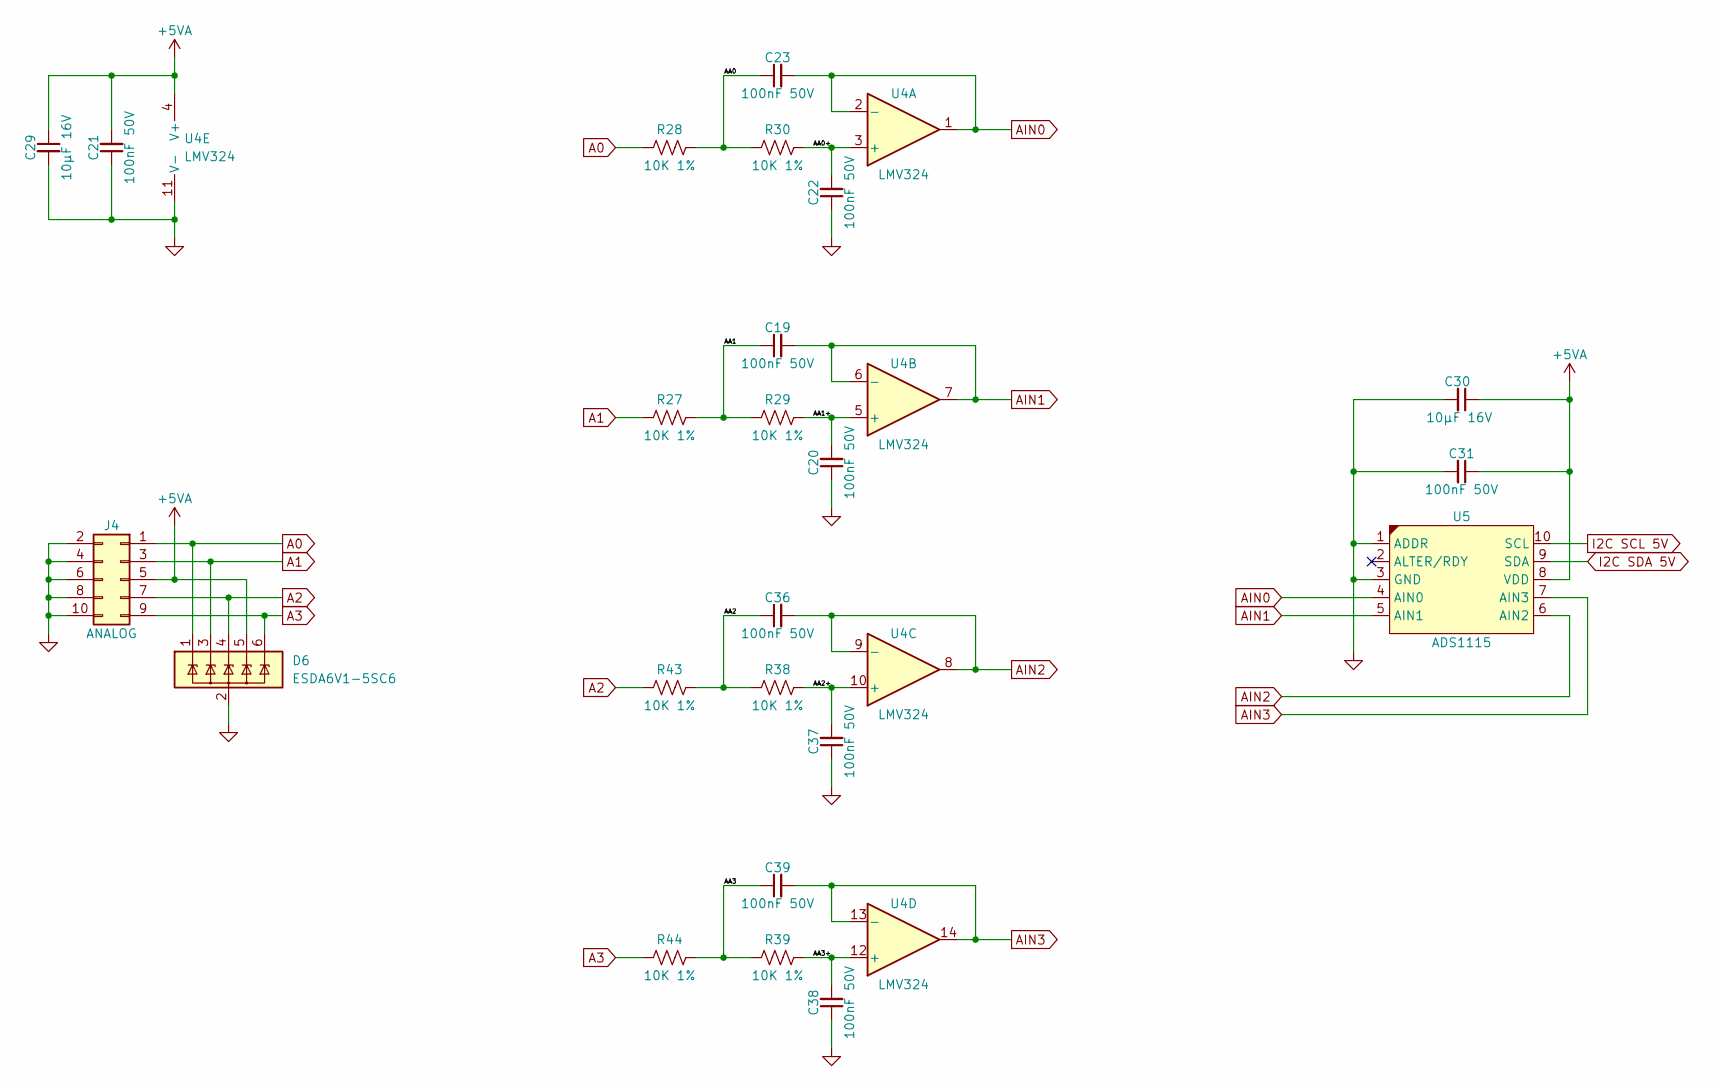
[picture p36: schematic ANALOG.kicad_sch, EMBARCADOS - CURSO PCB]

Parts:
C19, C20, C21, C22, C23, C31, C36, C37, C38, C39: 100nF 50V; C_0603_1608Metric; MPN KGM15BR71H104K; LCSC MPN CC0603KRX7R9BB104
C29, C30: 10µF 16V; C_0805_2012Metric; MPN KGM21AR71C106K; LCSC MPN CL21A106KAYNNNE
D6: ESDA6V1-5SC6; SOT-23-6; MPN ESDA6V1-5SC6; LCSC Part # C2827672
J4: ANALOG; PinSocket_2x05_P2.54mm_Horizontal; MPN 613010243121
R27, R28, R29, R30, R38, R39, R43, R44: 10K 1%; R_0603_1608Metric; MPN CRCW060310K0FK; LCSC Part # C25804
U4: LMV324; TSSOP-14_4.4x5mm_P0.65mm; MPN LMV324IPT; LCSC Part # C398929
U5: ADS1115; TSSOP-10_3x3mm_P0.5mm; MPN ADS1115IDGSR; LCSC Part # C37593

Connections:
+5VA: C21.2, C29.1, C30.1, C31.1, D6.5 (IO4), J4.5, U4.4 (V+), U5.8 (VDD); also elsewhere on the board
/ANALOG/AA0: C23.1, R28.2, R30.1
/ANALOG/AA0+: C22.2, R30.2, U4.3 (+)
/ANALOG/AA1: C19.1, R27.2, R29.1
/ANALOG/AA1+: C20.2, R29.2, U4.5 (+)
/ANALOG/AA2: C36.1, R38.1, R43.2
/ANALOG/AA2+: C37.2, R38.2, U4.10 (+)
/ANALOG/AA3: C39.1, R39.1, R44.2
/ANALOG/AA3+: C38.2, R39.2, U4.12 (+)
A0: D6.1 (IO1), J4.1, R28.1
A1: D6.3 (IO2), J4.3, R27.1
A2: D6.4 (IO3), J4.7, R43.1
A3: D6.6 (IO5), J4.9, R44.1
AIN0: C23.2, U4.1, U4.2 (-), U5.4 (AIN0)
AIN1: C19.2, U4.6 (-), U4.7, U5.5 (AIN1)
AIN2: C36.2, U4.8, U4.9 (-), U5.6 (AIN2)
AIN3: C39.2, U4.13 (-), U4.14, U5.7 (AIN3)
GND: C20.1, C21.1, C22.1, C29.2, C30.2, C31.2, C37.1, C38.1, D6.2 (GND), J4.2, J4.4, J4.6, J4.8, J4.10, U4.11 (V-), U5.1 (ADDR), U5.3 (GND); also elsewhere on the board
I2C SCL 5V: U5.10 (SCL); also elsewhere on the board
I2C SDA 5V: U5.9 (SDA); also elsewhere on the board

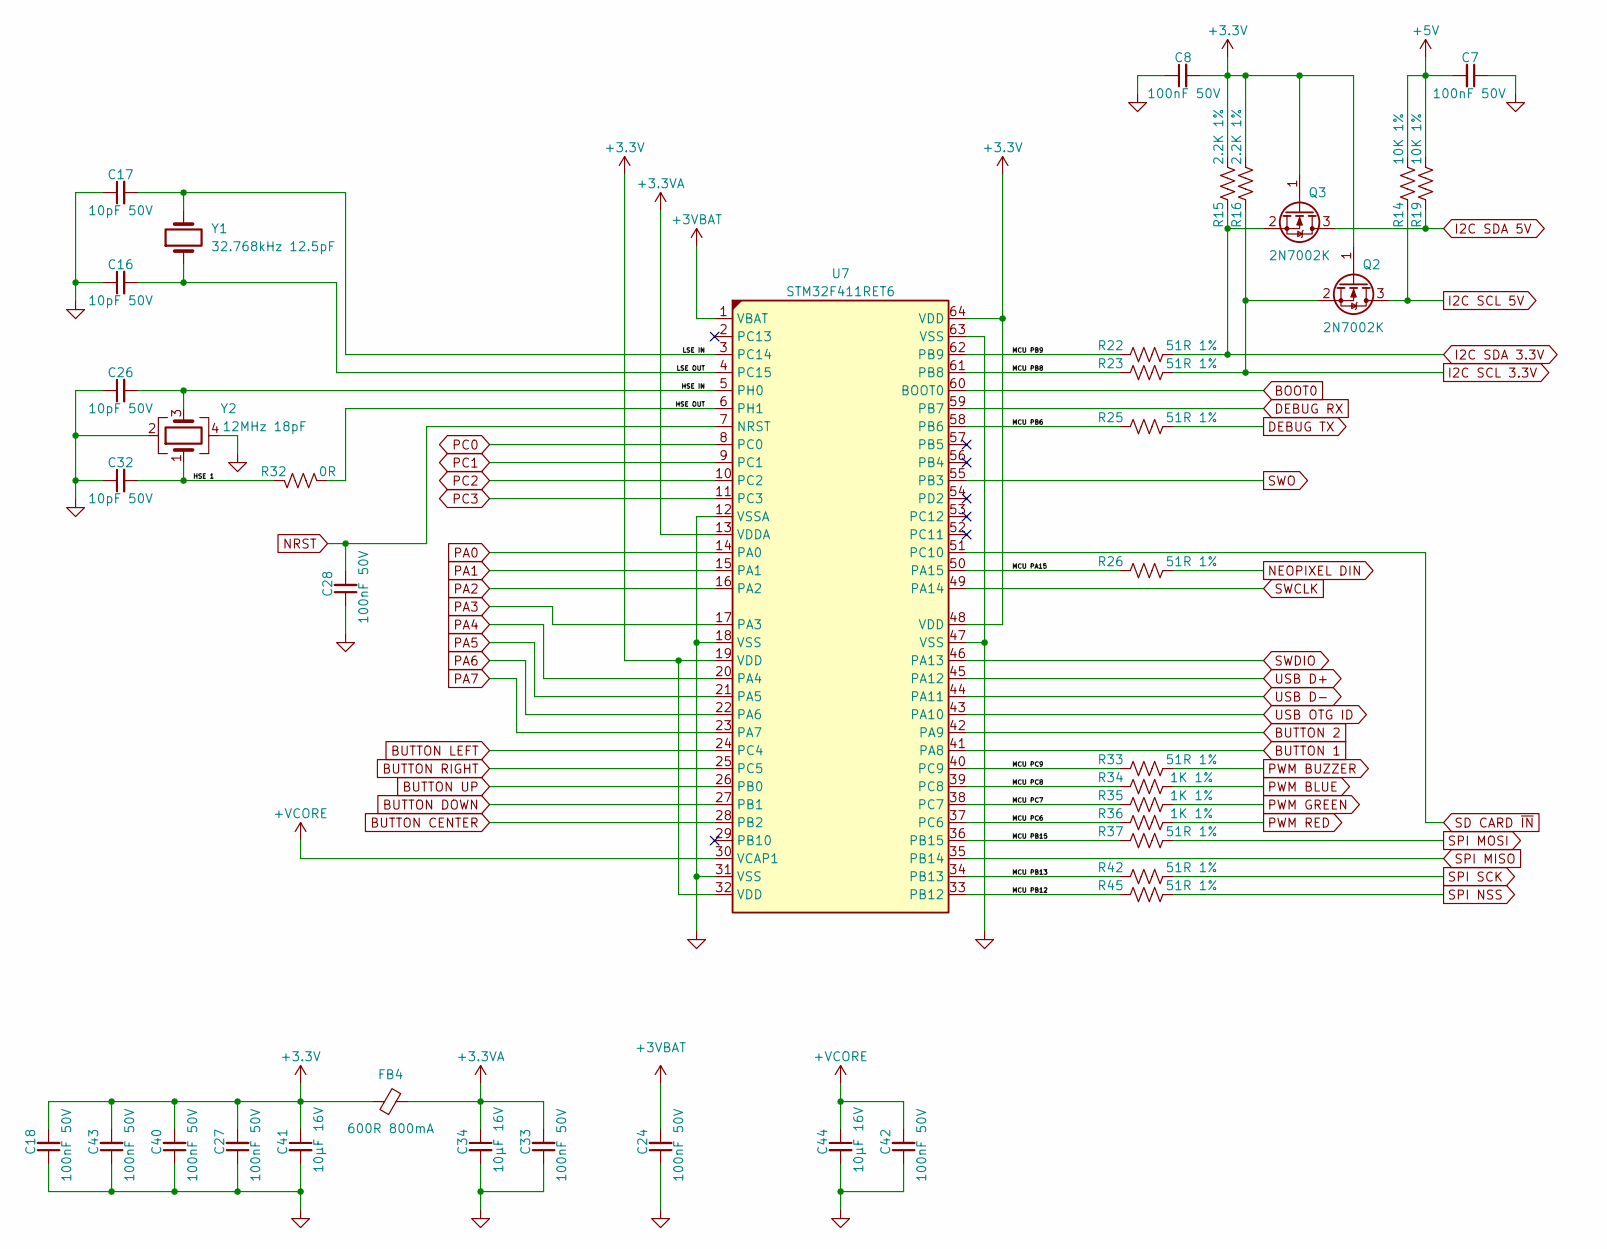
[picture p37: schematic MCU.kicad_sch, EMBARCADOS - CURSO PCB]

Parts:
C7, C8, C18, C24, C27, C28, C33, C40, C42, C43: 100nF 50V; C_0603_1608Metric; MPN KGM15BR71H104K; LCSC MPN CC0603KRX7R9BB104
C16, C17, C26, C32: 10pF 50V; C_0603_1608Metric; MPN KGM15ACG1H100G; LCSC MPN CL10C100JB8NNNC
C34, C41, C44: 10µF 16V; C_0805_2012Metric; MPN KGM21AR71C106K; LCSC MPN CL21A106KAYNNNE
FB4: 600R 800mA; L_0603_1608Metric; MPN 742792651; LCSC Part # C963865
Q2, Q3: 2N7002K; SOT-23; MPN 2N7002K-7; LCSC Part # C8545
R14, R19: 10K 1%; R_0603_1608Metric; MPN CRCW060310K0FK; LCSC Part # C25804
R15, R16: 2.2K 1%; R_0603_1608Metric; MPN CRCW06032K20FK; LCSC Part # C4190
R22, R23, R25, R26, R33, R37, R42, R45: 51R 1%; R_0603_1608Metric; MPN CRCW060351R0FK; LCSC Part # C23197
R32: 0R; R_0603_1608Metric; MPN CRCW06030000Z0; LCSC Part # C21189
R34, R35, R36: 1K 1%; R_0603_1608Metric; MPN CRCW06031K00FK; LCSC Part # C21190
U7: STM32F411RET6; LQFP-64_10x10mm_P0.5mm; MPN STM32F411RET6; LCSC Part # C94355
Y1: 32.768kHz 12.5pF; Crystal_SMD_3215-2Pin_3.2x1.5mm; MPN ABS06-32.768KHZ-T; LCSC Part # C5563819
Y2: 12MHz 18pF; Crystal_SMD_3225-4Pin_3.2x2.5mm; MPN ABM8-12.000MHZ-D2Y-T; LCSC MPN 3225 12M 18PF 20PPM

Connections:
+3.3V: C8.2, C18.2, C27.2, C40.2, C41.1, C43.2, FB4.1, Q2.1 (G), Q3.1 (G), R15.1, R16.1, U7.19 (VDD), U7.32 (VDD), U7.48 (VDD), U7.64 (VDD); also elsewhere on the board
+3.3VA: C33.2, C34.1, FB4.2, U7.13 (VDDA); also elsewhere on the board
+3VBAT: C24.2, U7.1 (VBAT); also elsewhere on the board
+5V: C7.2, R14.1, R19.1; also elsewhere on the board
+VCORE: C42.2, C44.1, U7.30 (VCAP1); also elsewhere on the board
/MCU/HSE 1: C32.2, R32.1, Y2.1
/MCU/HSE IN: C26.2, U7.5 (PH0), Y2.3
/MCU/HSE OUT: R32.2, U7.6 (PH1)
/MCU/LSE IN: C17.2, U7.3 (PC14), Y1.2
/MCU/LSE OUT: C16.2, U7.4 (PC15), Y1.1
/MCU/MCU PA15: R26.1, U7.50 (PA15)
/MCU/MCU PB6: R25.1, U7.58 (PB6)
/MCU/MCU PB8: R23.1, U7.61 (PB8)
/MCU/MCU PB9: R22.1, U7.62 (PB9)
/MCU/MCU PB12: R45.1, U7.33 (PB12)
/MCU/MCU PB13: R42.1, U7.34 (PB13)
/MCU/MCU PB15: R37.1, U7.36 (PB15)
/MCU/MCU PC6: R36.1, U7.37 (PC6)
/MCU/MCU PC7: R35.1, U7.38 (PC7)
/MCU/MCU PC8: R34.1, U7.39 (PC8)
/MCU/MCU PC9: R33.1, U7.40 (PC9)
BOOT0: U7.60 (BOOT0); also elsewhere on the board
BUTTON 1: U7.41 (PA8); also elsewhere on the board
BUTTON 2: U7.42 (PA9); also elsewhere on the board
BUTTON CENTER: U7.28 (PB2); also elsewhere on the board
BUTTON DOWN: U7.27 (PB1); also elsewhere on the board
BUTTON LEFT: U7.24 (PC4); also elsewhere on the board
BUTTON RIGHT: U7.25 (PC5); also elsewhere on the board
BUTTON UP: U7.26 (PB0); also elsewhere on the board
DEBUG RX: U7.59 (PB7); also elsewhere on the board
DEBUG TX: R25.2; also elsewhere on the board
GND: C7.1, C8.1, C16.1, C17.1, C18.1, C24.1, C26.1, C27.1, C28.1, C32.1, C33.1, C34.2, C40.1, C41.2, C42.1, C43.1, C44.2, U7.12 (VSSA), U7.18 (VSS), U7.31 (VSS), U7.47 (VSS), U7.63 (VSS), Y2.2, Y2.4; also elsewhere on the board
I2C SCL 3.3V: Q2.2 (S), R16.2, R23.2; also elsewhere on the board
I2C SCL 5V: Q2.3 (D), R14.2; also elsewhere on the board
I2C SDA 3.3V: Q3.2 (S), R15.2, R22.2; also elsewhere on the board
I2C SDA 5V: Q3.3 (D), R19.2; also elsewhere on the board
NEOPIXEL DIN: R26.2; also elsewhere on the board
NRST: C28.2, U7.7 (NRST); also elsewhere on the board
PA0: U7.14 (PA0); also elsewhere on the board
PA1: U7.15 (PA1); also elsewhere on the board
PA2: U7.16 (PA2); also elsewhere on the board
PA3: U7.17 (PA3); also elsewhere on the board
PA4: U7.20 (PA4); also elsewhere on the board
PA5: U7.21 (PA5); also elsewhere on the board
PA6: U7.22 (PA6); also elsewhere on the board
PA7: U7.23 (PA7); also elsewhere on the board
PC0: U7.8 (PC0); also elsewhere on the board
PC1: U7.9 (PC1); also elsewhere on the board
PC2: U7.10 (PC2); also elsewhere on the board
PC3: U7.11 (PC3); also elsewhere on the board
PWM BLUE: R34.2; also elsewhere on the board
PWM BUZZER: R33.2; also elsewhere on the board
PWM GREEN: R35.2; also elsewhere on the board
PWM RED: R36.2; also elsewhere on the board
SD CARD ~IN: U7.51 (PC10); also elsewhere on the board
SPI MISO: U7.35 (PB14); also elsewhere on the board
SPI MOSI: R37.2; also elsewhere on the board
SPI NSS: R45.2; also elsewhere on the board
SPI SCK: R42.2; also elsewhere on the board
SWCLK: U7.49 (PA14); also elsewhere on the board
SWDIO: U7.46 (PA13); also elsewhere on the board
SWO: U7.55 (PB3); also elsewhere on the board
USB D+: U7.45 (PA12); also elsewhere on the board
USB D-: U7.44 (PA11); also elsewhere on the board
USB OTG ID: U7.43 (PA10); also elsewhere on the board

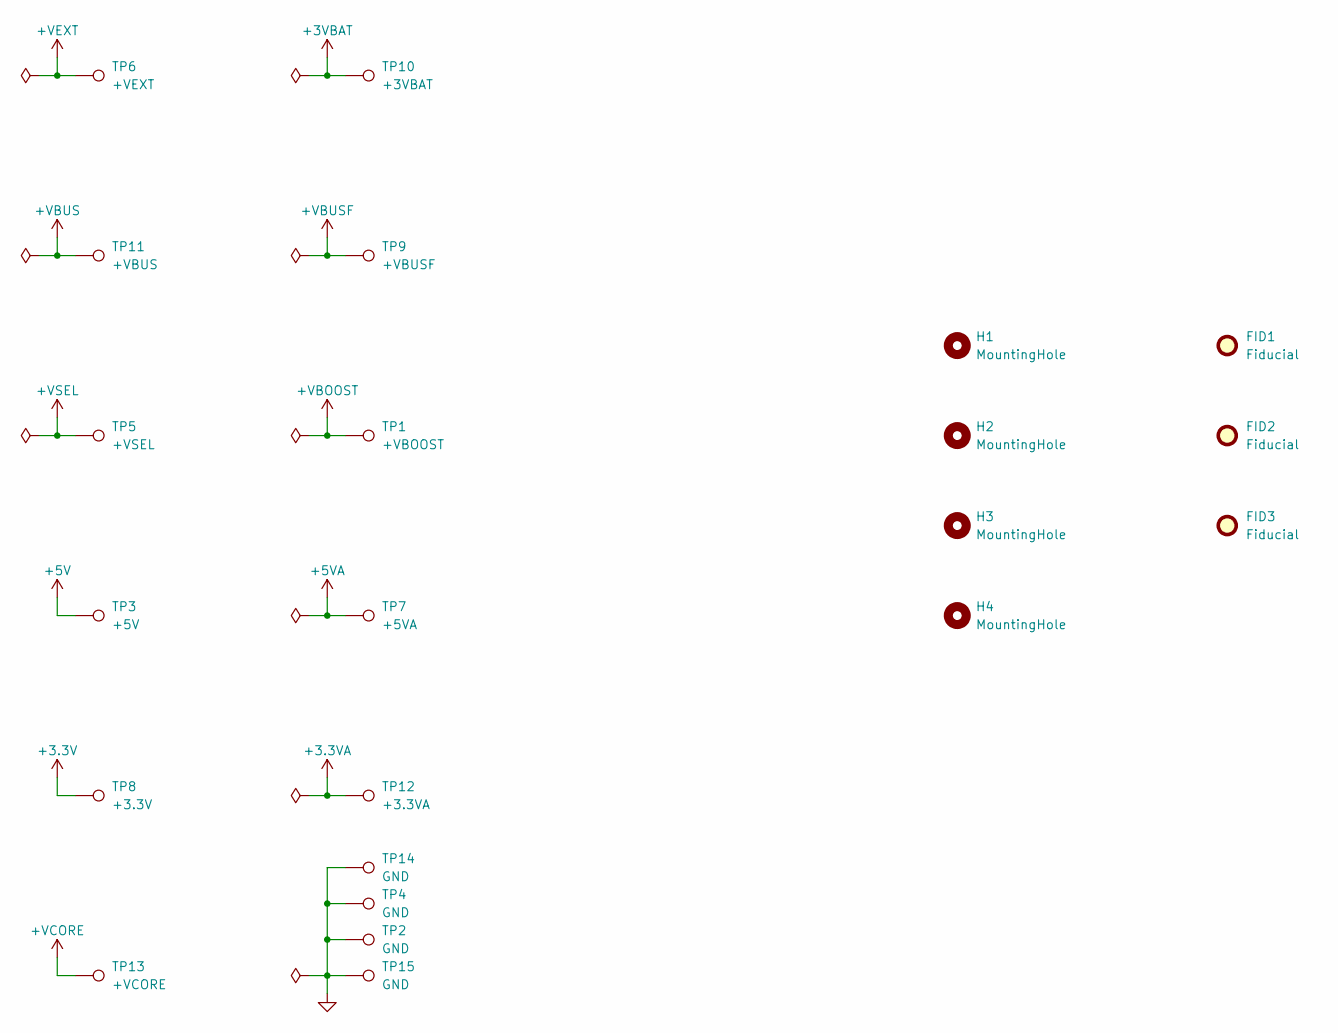
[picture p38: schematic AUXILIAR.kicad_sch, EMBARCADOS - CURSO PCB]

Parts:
FID1, FID2, FID3: Fiducial; Fiducial_0.75mm_Mask1.5mm
H1, H2, H3, H4: MountingHole; MountingHole_3.2mm_M3
TP1: +VBOOST; TestPoint_Keystone_5000-5004_Miniature
TP2, TP4, TP14, TP15: GND; TestPoint_Keystone_5000-5004_Miniature
TP3: +5V; TestPoint_Keystone_5000-5004_Miniature
TP5: +VSEL; TestPoint_Keystone_5000-5004_Miniature
TP6: +VEXT; TestPoint_Keystone_5000-5004_Miniature
TP7: +5VA; TestPoint_Keystone_5000-5004_Miniature
TP8: +3.3V; TestPoint_Keystone_5000-5004_Miniature
TP9: +VBUSF; TestPoint_Keystone_5000-5004_Miniature
TP10: +3VBAT; TestPoint_Keystone_5000-5004_Miniature
TP11: +VBUS; TestPoint_Keystone_5000-5004_Miniature
TP12: +3.3VA; TestPoint_Keystone_5000-5004_Miniature
TP13: +VCORE; TestPoint_Keystone_5000-5004_Miniature

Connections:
+3.3V: TP8.1; also elsewhere on the board
+3.3VA: TP12.1; also elsewhere on the board
+3VBAT: TP10.1; also elsewhere on the board
+5V: TP3.1; also elsewhere on the board
+5VA: TP7.1; also elsewhere on the board
+VBOOST: TP1.1; also elsewhere on the board
+VBUS: TP11.1; also elsewhere on the board
+VBUSF: TP9.1; also elsewhere on the board
+VCORE: TP13.1; also elsewhere on the board
+VEXT: TP6.1; also elsewhere on the board
+VSEL: TP5.1; also elsewhere on the board
GND: TP2.1, TP4.1, TP14.1, TP15.1; also elsewhere on the board

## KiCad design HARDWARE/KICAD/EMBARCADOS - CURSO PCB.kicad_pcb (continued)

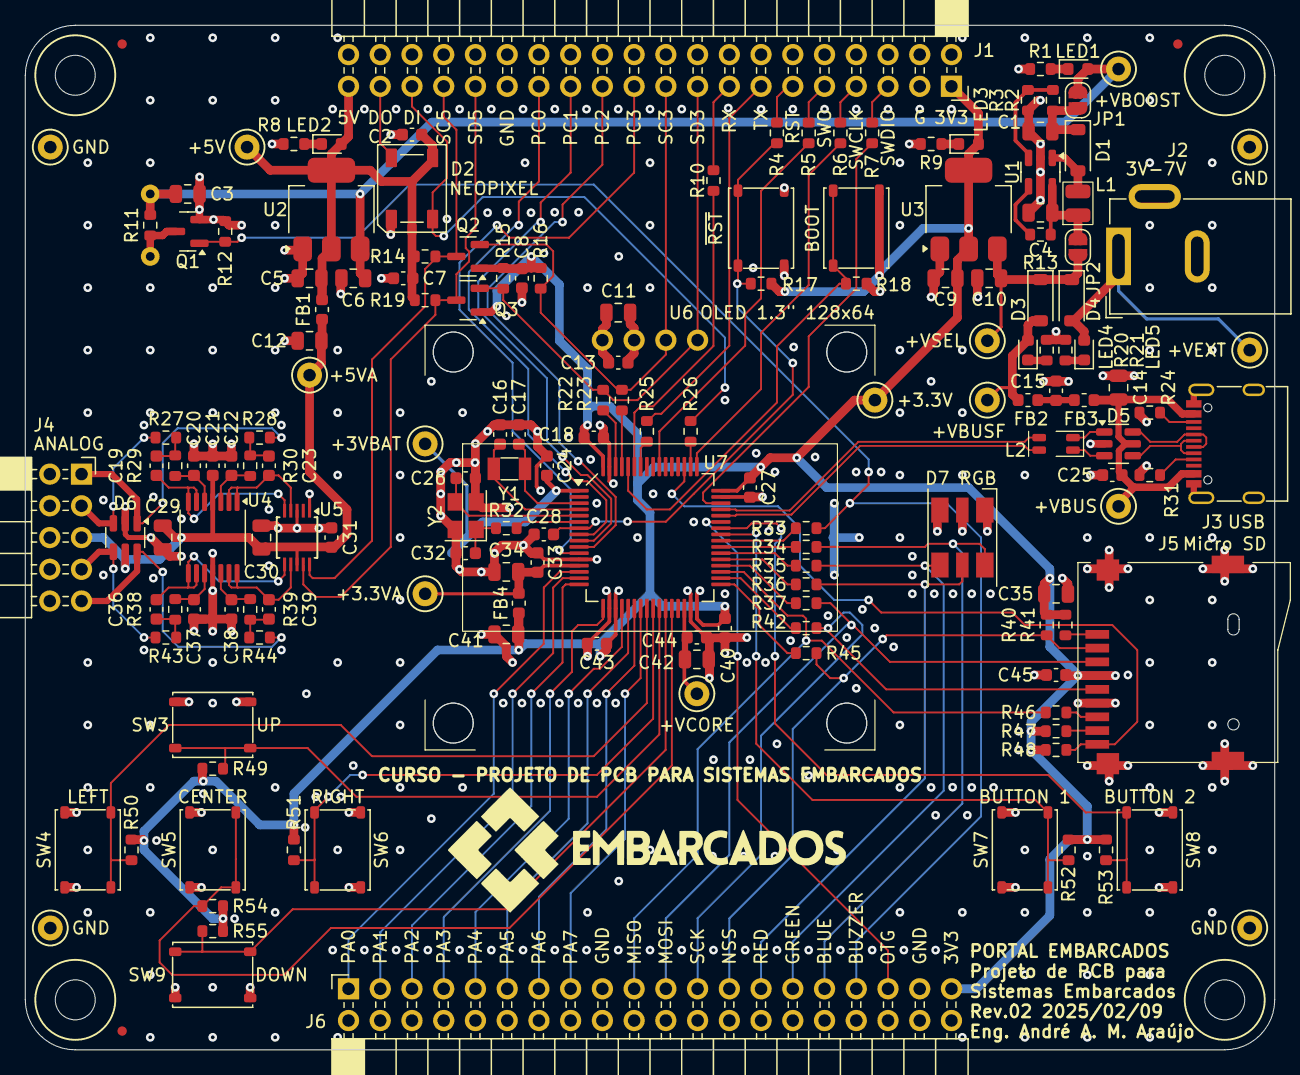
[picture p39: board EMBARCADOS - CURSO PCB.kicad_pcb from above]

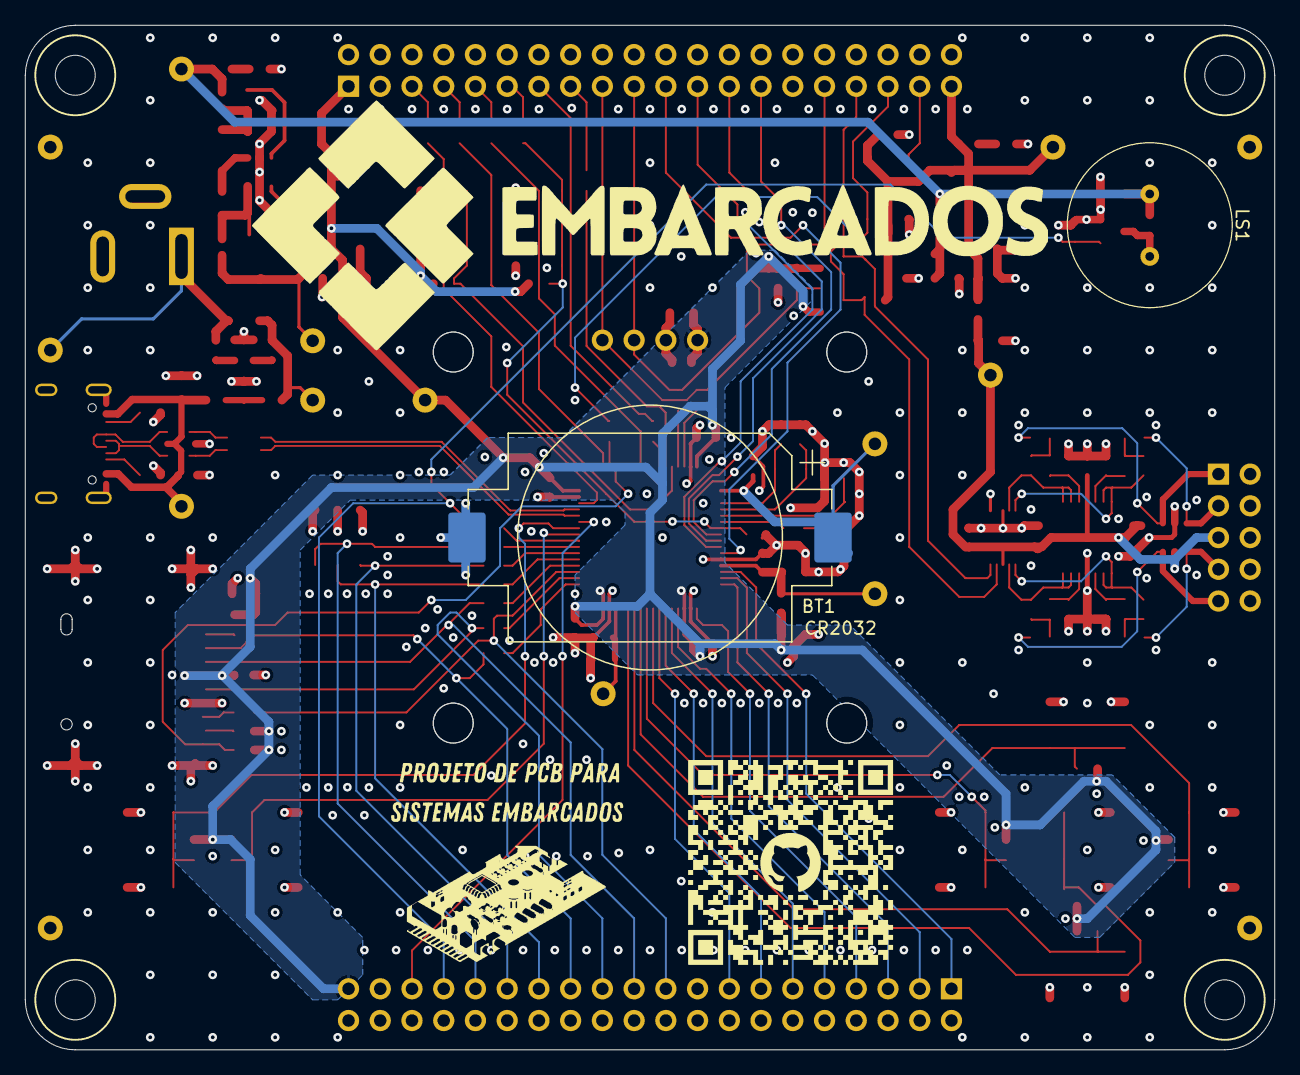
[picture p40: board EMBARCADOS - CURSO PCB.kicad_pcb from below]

Board: 4 copper layers, 100.0 x 82.0 mm, 171 parts (2 on the bottom side), 114 nets.

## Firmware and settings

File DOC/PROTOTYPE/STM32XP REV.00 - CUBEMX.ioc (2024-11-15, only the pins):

Mcu.UserName=STM32F411RETx
PA0-WKUP.Signal=ADCx_IN0
PA1.Signal=ADCx_IN1
PA10.Signal=USB_OTG_FS_ID
PA11.Signal=USB_OTG_FS_DM
PA12.Signal=USB_OTG_FS_DP
PA13.Signal=SYS_JTMS-SWDIO
PA14.Signal=SYS_JTCK-SWCLK
PA15.Signal=S_TIM2_CH1_ETR
PA2.Signal=ADCx_IN2
PA3.Signal=ADCx_IN3
PA4.Signal=ADCx_IN4
PA5.Signal=ADCx_IN5
PA6.Signal=ADCx_IN6
PA7.Signal=ADCx_IN7
PA8.Signal=GPXTI8
PA9.Signal=GPXTI9
PB0.Signal=GPXTI0
PB1.Signal=GPXTI1
PB10.Signal=S_TIM2_CH3
PB12.Signal=SPI2_NSS
PB13.Signal=SPI2_SCK
PB14.Signal=SPI2_MISO
PB15.Signal=SPI2_MOSI
PB2.Signal=GPXTI2
PB3.Signal=SYS_JTDO-SWO
PB6.Signal=USART1_TX
PB7.Signal=USART1_RX
PB8.Signal=I2C1_SCL
PB9.Signal=I2C1_SDA
PC14-OSC32_IN.Signal=RCC_OSC32_IN
PC15-OSC32_OUT.Signal=RCC_OSC32_OUT
PC4.Signal=GPXTI4
PC5.Signal=GPXTI5
PC6.Signal=S_TIM3_CH1
PC7.Signal=S_TIM3_CH2
PC8.Signal=S_TIM3_CH3
PC9.Signal=S_TIM3_CH4

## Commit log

2024-11-09 Adding first files; just stared component library creation.
    [EMBARCADOS - CURSO PCB.kicad_pcb, EMBARCADOS - CURSO PCB.kicad_sch]
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2024-11-10 Added 3D model files and included them on respective footprints.
    [C&K PTS526SM20SMTR21LFS.igs, Display_OLED_SSD1306_1.3inch.STEP, MURATA PKM13EPYH4000-A0.STEP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]
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2024-11-10 Added material about the prototype.
    [STM32XP REV.00 - BOM.xlsx]
2024-11-12 Started schematic capture.
    [EMBARCADOS - CURSO PCB.kicad_sch]
2024-11-12 Finished 1st pass of the power circuits. 3 classes recorded.
    [EMBARCADOS - CURSO PCB.kicad_sch]
2024-11-14 Re-recorded class 07.03 due to audio error.
    [EMBARCADOS - CURSO PCB.kicad_sch]
2024-11-14 Added POWER and MCU sheets. Added MCU, decoupling capacitors and crystals.
    [EMBARCADOS - CURSO PCB.kicad_sch, MCU.kicad_sch, POWER.kicad_sch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]
2024-11-14 Preparation for recording about labels.
    [MCU.kicad_sch]
2024-11-14 POWER sheet refactoring.
    [MCU.kicad_sch, POWER.kicad_sch]
2024-11-15 Added IO connections to MCU; fixed MCU pins order on the library.
    [MCU.kicad_sch, POWER.kicad_sch]
2024-11-15 Fixed MCU pins on schematic and routed I2C voltage translator.
    [MCU.kicad_sch]
2024-11-15 Refactoring. Added STM32XP.ioc.
    [MCU.kicad_sch, POWER.kicad_sch]
2024-11-15 Recorded IO sheet class.
    [EMBARCADOS - CURSO PCB.kicad_sch, IO.kicad_sch, POWER.kicad_sch]
2024-11-15 Added ANALOG and INTERFACE sheets.
    [ANALOG.kicad_sch, EMBARCADOS - CURSO PCB.kicad_sch, INTERFACE.kicad_sch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]
2024-11-15 Finished schematic.
    [ANALOG.kicad_sch, AUXILIAR.kicad_sch, EMBARCADOS - CURSO PCB.kicad_sch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]
2024-11-16 Refactoring of schematic. PDF plotting.
    [AUXILIAR.kicad_sch, POWER.kicad_sch]
2024-11-16 Starting PCB layout.
    [AUXILIAR.kicad_sch, EMBARCADOS - CURSO PCB.kicad_pcb, MCU.kicad_sch]
2024-11-16 Did MCU positioning.
    [EMBARCADOS - CURSO PCB.kicad_pcb]
2024-11-16 Did IO positioning.
    [IO.kicad_sch]
2024-11-16 Did ANALOG positioning.
    [EMBARCADOS - CURSO PCB.kicad_pcb, IO.kicad_sch]
2024-11-16 Did overal positioning inside the board.
    [EMBARCADOS - CURSO PCB.kicad_pcb]
2024-11-16 Finished initial positioning.
    [EMBARCADOS - CURSO PCB.kicad_pcb, INTERFACE.kicad_sch]
2024-11-17 Preparations for starting PCB routing.
    [EMBARCADOS - CURSO PCB.kicad_pcb, WE 613040243121 (rev1).iges]
2024-11-17 Recorded Class 08.06 Part 1.
    [EMBARCADOS - CURSO PCB.kicad_pcb, IO.kicad_sch]
2024-11-17 Recorded Class 08.06 Part 2.
    [EMBARCADOS - CURSO PCB.kicad_pcb]
2024-11-17 Recorded Class 08.06 Part 3.
    [EMBARCADOS - CURSO PCB.kicad_pcb]
2024-11-17 Recorded Class 08.06 Part 4.
    [EMBARCADOS - CURSO PCB.kicad_pcb]
2024-11-17 Recorded Class 08.06 Part 6.
    [EMBARCADOS - CURSO PCB.kicad_pcb]
2024-11-18 Recorded Class 08.07 Part 1.
    [EMBARCADOS - CURSO PCB.kicad_pcb]
2024-11-22 Routing detailing before Class 08.07 Part 2.
    [EMBARCADOS - CURSO PCB.kicad_pcb]
2024-11-22 Refactoring before Class 08.07 Part 3.
    [EMBARCADOS - CURSO PCB.kicad_pcb]
2024-11-22 Refactoring before Class 08.07 Part 4.
    [EMBARCADOS - CURSO PCB.kicad_pcb]
2024-11-22 Recorded Class 08.07 Part 5.
    [ANALOG.kicad_sch, AUXILIAR.kicad_sch, EMBARCADOS - CURSO PCB.kicad_pcb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]
2024-11-23 Refactoring after Class 08.07 Part 5.
    [ANALOG.kicad_sch, AUXILIAR.kicad_sch, EMBARCADOS - CURSO PCB.kicad_pcb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]
2024-11-23 Refactoring before Class 08.07 Part 6.
    [EMBARCADOS - CURSO PCB.kicad_pcb, INTERFACE.kicad_sch]
2024-11-23 Finished PCB Layout.
    [EMBARCADOS - CURSO PCB.kicad_pcb, INTERFACE.kicad_sch, IO.kicad_sch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]
2024-11-24 Recorded Class 09.10.
    [EMBARCADOS - CURSO PCB.kicad_pcb]
2024-11-24 Generated Gerber and Drill files.
    [EMBARCADOS - CURSO PCB-B_Mask.gbr, EMBARCADOS - CURSO PCB-B_Paste.gbr, EMBARCADOS - CURSO PCB-B_Silkscreen.gbr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]
2024-11-24 Regenerated Gerber and Drill files.
    [EMBARCADOS - CURSO PCB-B_Mask.gbr, EMBARCADOS - CURSO PCB-B_Paste.gbr, EMBARCADOS - CURSO PCB-B_Silkscreen.gbr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]
2024-11-30 Fixed gerbers for silkscreen subtraction and added Netlist file.
    [EMBARCADOS - CURSO PCB-B_Mask.gbr, EMBARCADOS - CURSO PCB-B_Paste.gbr, EMBARCADOS - CURSO PCB-B_Silkscreen.gbr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]
2024-11-30 Created BOM.
    [EMBARCADOS - CURSO PCB - BOM.xlsx, EMBARCADOS - CURSO PCB.csv]
2024-12-01 Generated BOM, Pick-And-Place and Gerber files for JLCPCB.
    [EMBARCADOS - CURSO PCB - BOM (JLCPCB).xlsx, EMBARCADOS - CURSO PCB - BOM.xlsx, EMBARCADOS - CURSO PCB - PICK AND PLACEs (JLCPCB).xlsx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]
2024-12-01 Added JLCPCB sample BOM and CPL files.
    [Sample-BOM_JLCSMT.xlsx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]
2024-12-03 Testing PDF generation and STEP file export. Testing STEP file on Solid Edge.
    [EMBARCADOS - CURSO PCB.cfg]
2024-12-03 Removed 3D CAD folder for next classes recordings.
    [EMBARCADOS - CURSO PCB.cfg]
2024-12-05 Recorded Class 09.08. Generated PDFs for schematic and layout.
    [EMBARCADOS - CURSO PCB.kicad_pcb, POWER.kicad_sch]
2024-12-05 Created STEP file and mechanical drawing from Solid Edge.
    [EMBARCADOS - CURSO PCB.cfg]
2025-01-05 Updated logos with higher resolution images.
    [EMBARCADOS - CURSO PCB.kicad_pcb]
2025-01-05 Added QR code for project repo on GitHub. Changed board revision to 01 2025.01.05.
    [EMBARCADOS - CURSO PCB.kicad_pcb]
2025-01-05 Changed shcematic revision to 01 2025.01.05.
    [ANALOG.kicad_sch, AUXILIAR.kicad_sch, EMBARCADOS - CURSO PCB.kicad_sch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]
2025-01-05 Finished overall project review for PCB fabrication at JLCPCB.
    [ANALOG.kicad_sch, EMBARCADOS - CURSO PCB - BOM (JLCPCB).xlsx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]
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2025-02-09 Revision 02: fixed minor issues with D2 and U6 symbols/footprints. Generated new gerber and Drill files. Generated new PDF files of schematic and layout.
    [ANALOG.kicad_sch, AUXILIAR.kicad_sch, EMBARCADOS - CURSO PCB - BOM (JLCPCB).xlsx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]

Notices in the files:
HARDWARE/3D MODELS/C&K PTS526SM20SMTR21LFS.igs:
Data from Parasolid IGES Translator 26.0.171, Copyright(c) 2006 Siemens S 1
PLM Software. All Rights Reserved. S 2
